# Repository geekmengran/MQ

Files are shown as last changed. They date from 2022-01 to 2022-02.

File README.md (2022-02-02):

### MangoPi Nezha-MQ

### Introduction

This micro development board is specially designed to run Linux. Despite a mini body, it has all the vital functions. Equipped with D1s(RISC-V core) as the maincontroller chip, the board offers various commonly-used peripheral ports: GPIO, I2C & SPI, SDIO, Audio port(record, play), Video(RGB666 Display, touch, DVP, DSI and LVDS), USB Host, OTG, etc. Besides, the board comes with a built-in 64MB DDR and onboard WiFi, which fully supports Linux ecology and running complete Python.

### Spectification
  * D1s with 64MB DDR, RISC-V core up to 1GHz
  * Type-C USB-OTG and HOST
  * 22Pin expand x2(all pins out)
  * TF card
  * RTL8189F WiFi or other WiFi/BT module
  * FPC connector 15Pins DSI, 40Pins RGB, 24Pins DVP/RMII, 6Pins CTP
  * MIC and Audio OUT
  * Fel,reset button
  * 4x4cm size

### PCB
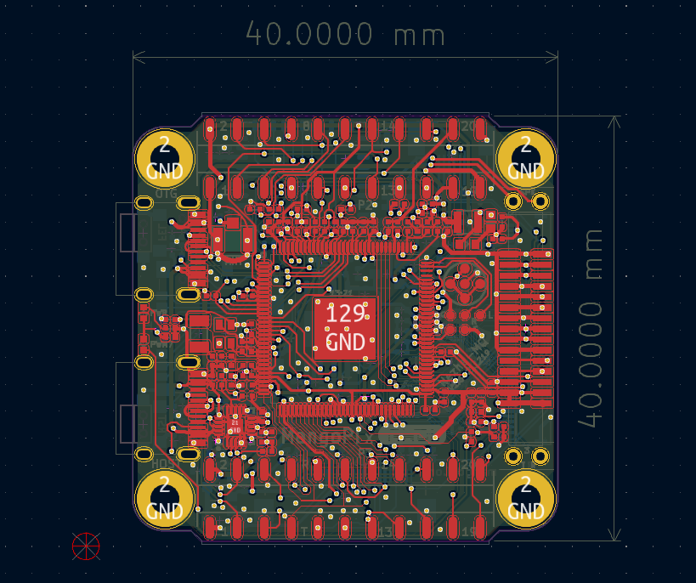
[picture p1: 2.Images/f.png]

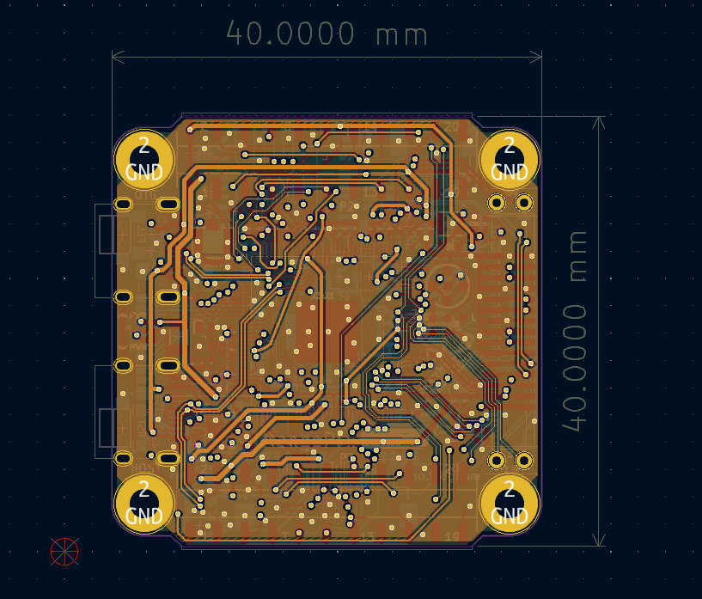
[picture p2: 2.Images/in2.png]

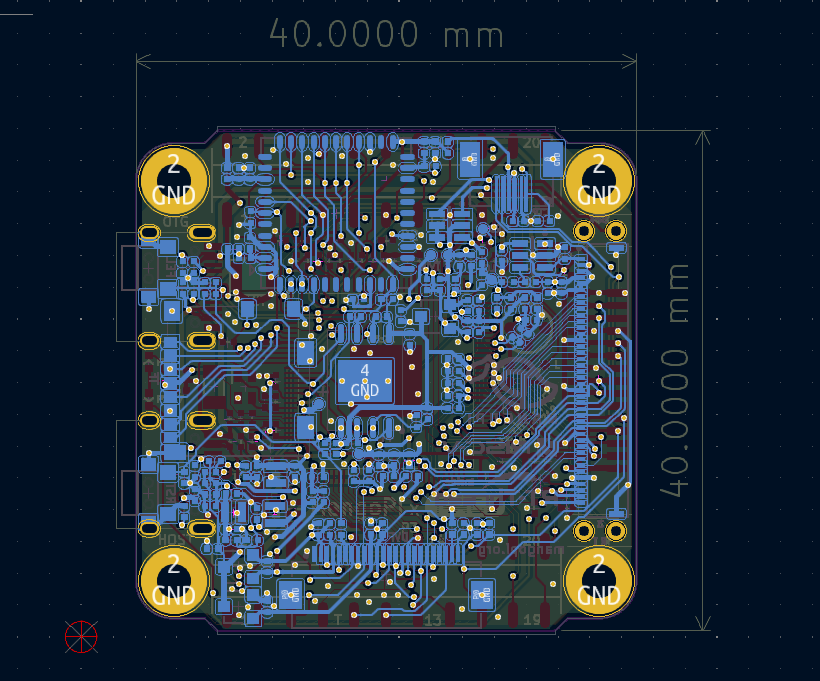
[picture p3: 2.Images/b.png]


### SCH
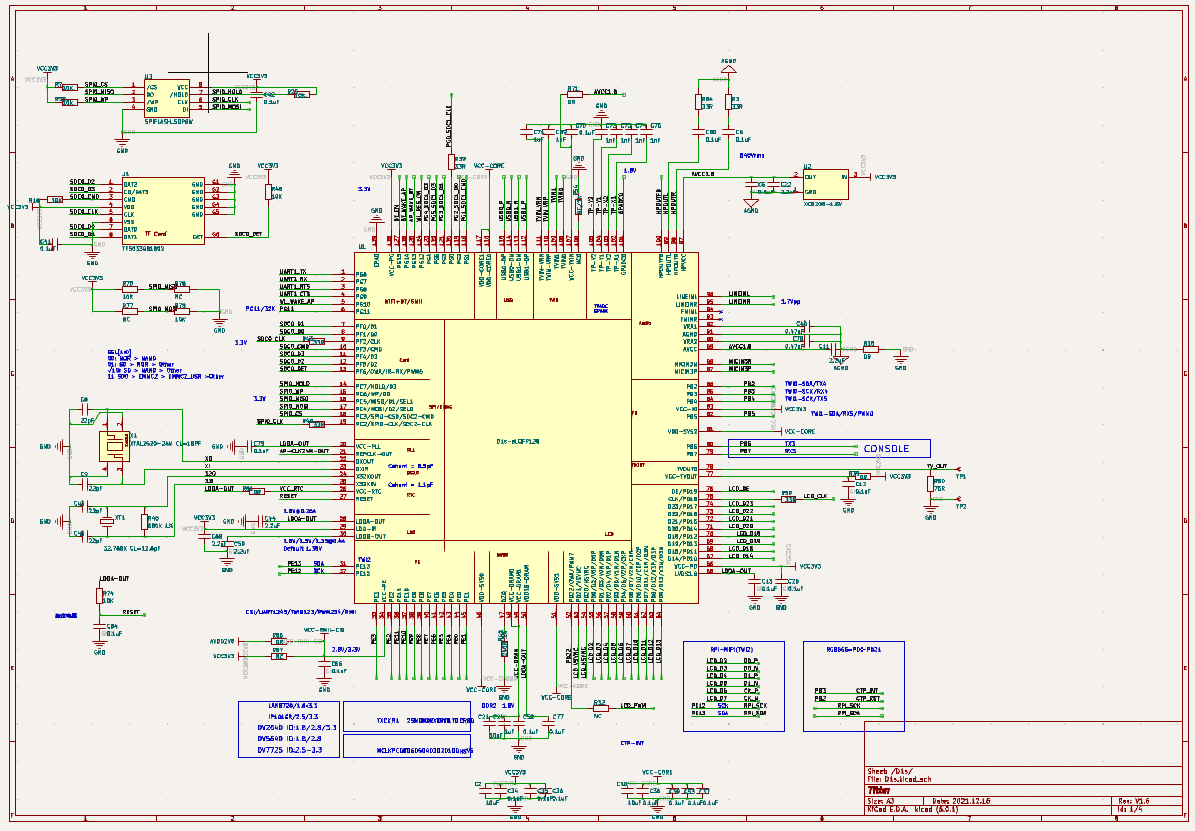
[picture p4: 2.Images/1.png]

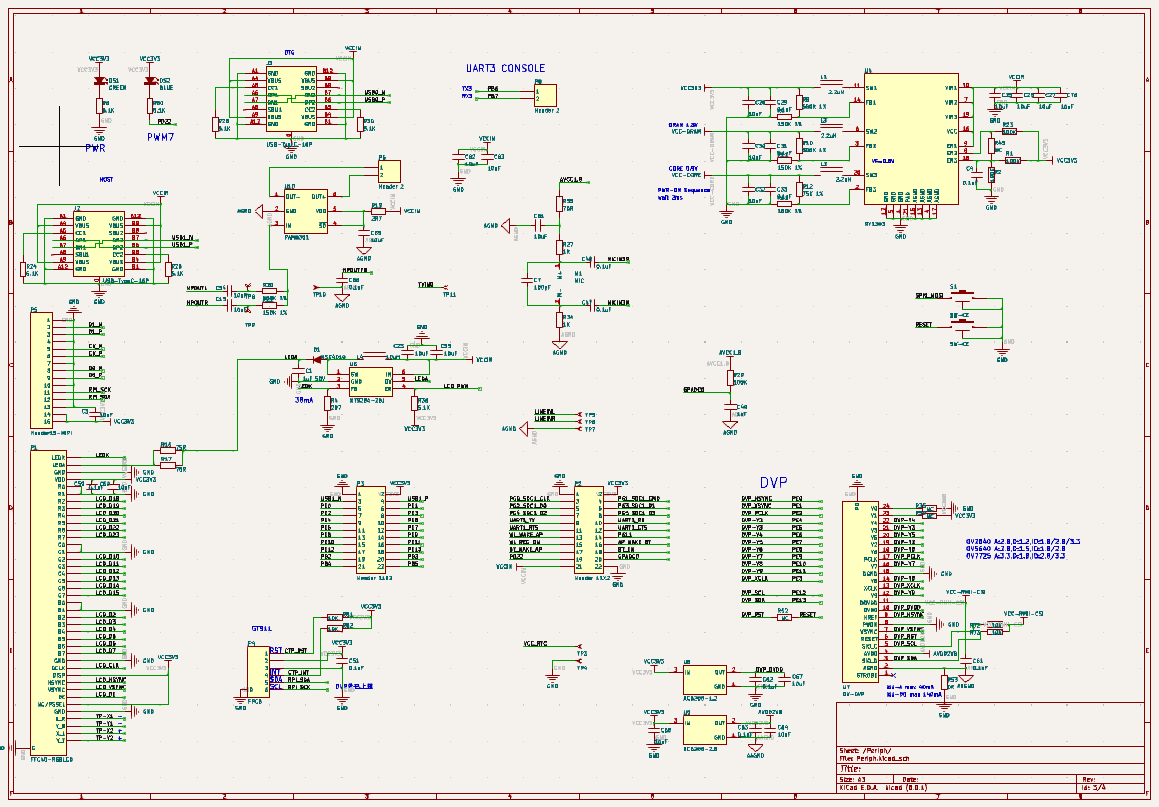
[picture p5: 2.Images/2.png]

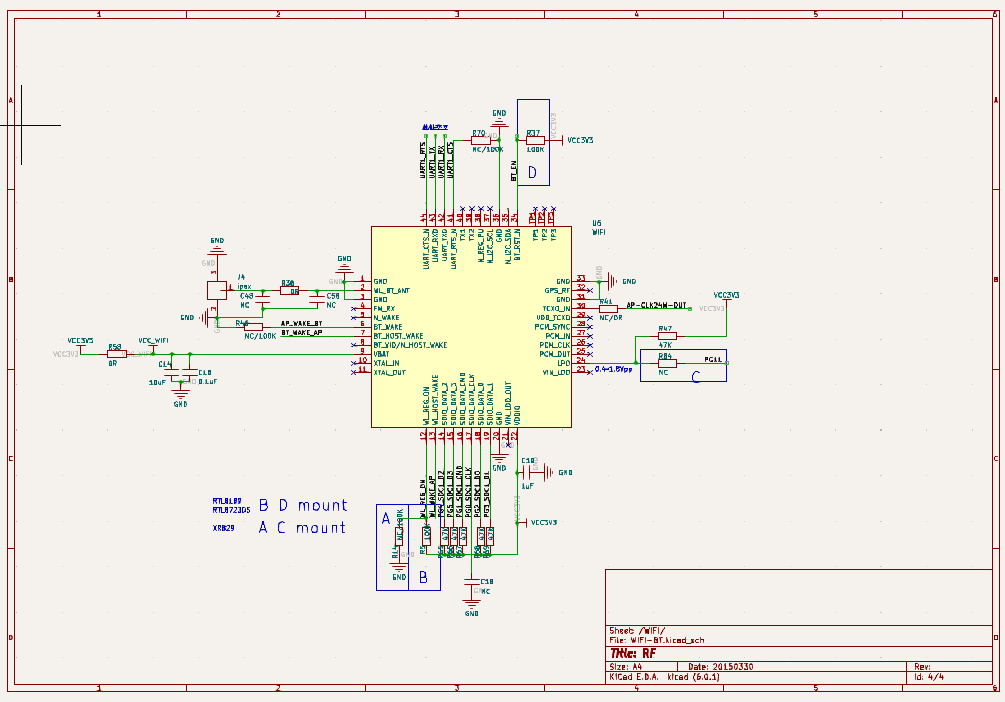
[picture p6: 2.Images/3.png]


### V1.6 Mass-Production
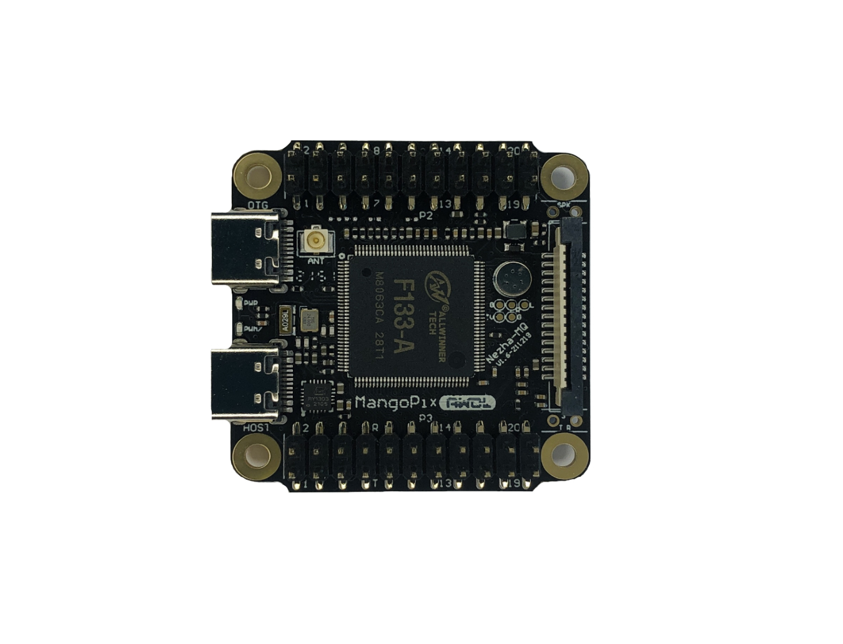
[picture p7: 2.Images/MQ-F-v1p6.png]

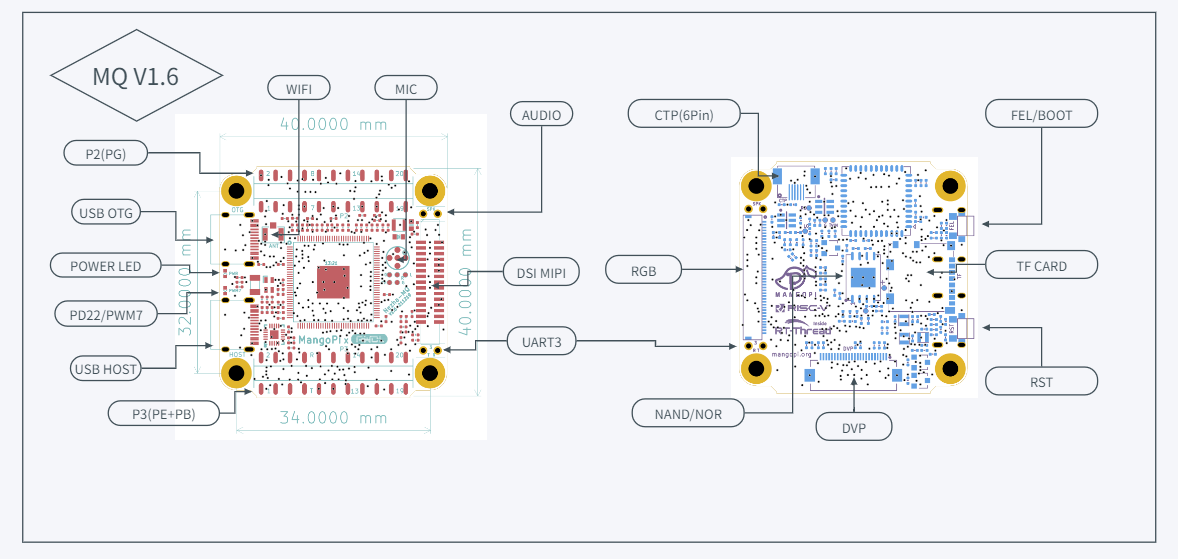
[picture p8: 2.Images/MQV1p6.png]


### MQ on the web
  * [mass-production on twitter]( https://twitter.com/mangopi_sbc/status/1469197984303022080)
  * [A shell](https://twitter.com/mangopi_sbc/status/1472535322605273090)
  * [MoeOS on MQ](https://www.lirui.tech/post/2021/12/MoeOS%E6%90%AC%E5%AE%B6%E5%88%B0Nezha-MQ%E4%B8%8A%E5%95%A6%EF%BC%88D1s%E8%A3%B8%E6%9C%BA%E7%A8%8B%E5%BA%8F%E6%89%A7%E8%A1%8C%EF%B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)
  * [Getting started on MQ with Tina-Linux](https://whycan.com/t_7575.html)
  * [use MQ drive RGB display](https://blog.csdn.net/qq_34440409/article/details/122021748)
  * [MQ first experience](https://www.neko.ooo/mongopi-mq1-hands-on/)
  * [RT-Thread on MQ](https://bbs.aw-ol.com/topic/908/)
  * [MQ's MIPI-DSI](https://bbs.aw-ol.com/topic/808/)
  * [more on Twitter](https://twitter.com/search?q=mangopi)

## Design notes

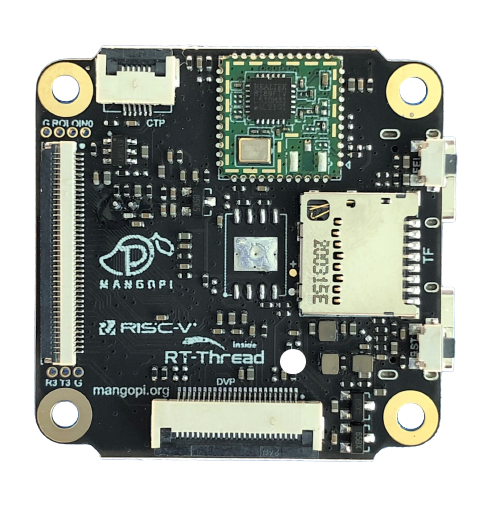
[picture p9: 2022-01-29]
2.Images/MQ-B-v1p5.png

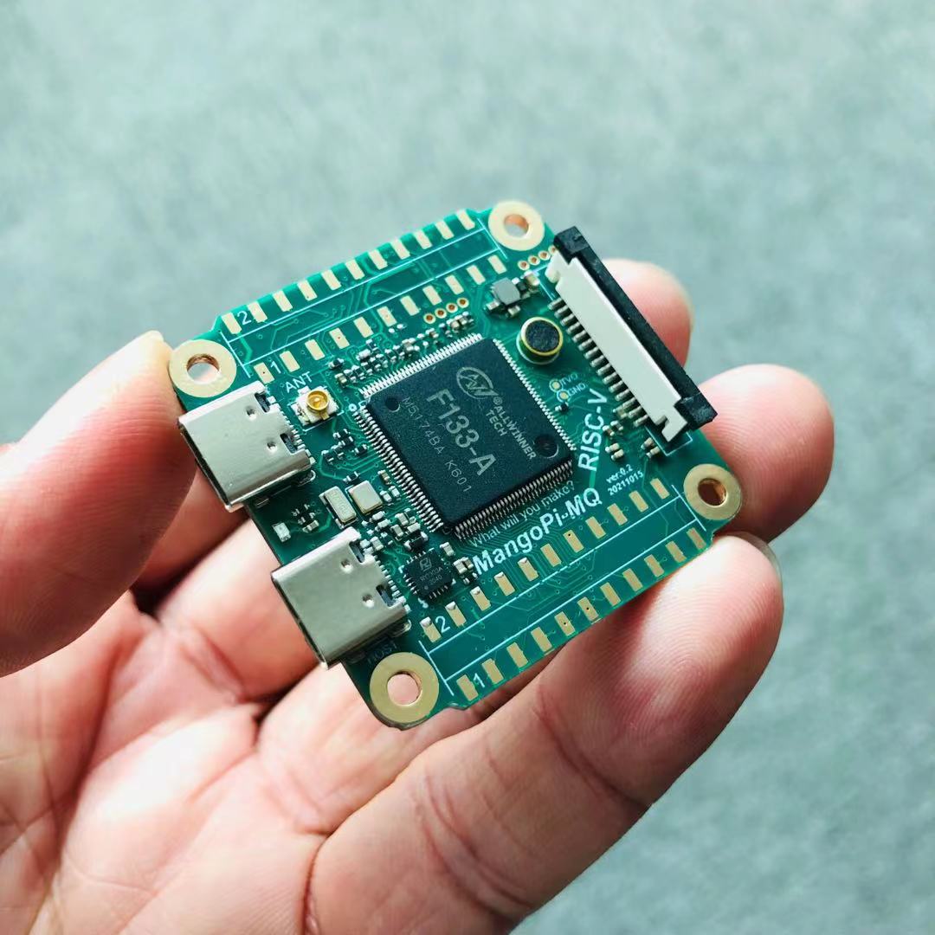
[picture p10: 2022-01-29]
2.Images/v0p2_first_run.jpg

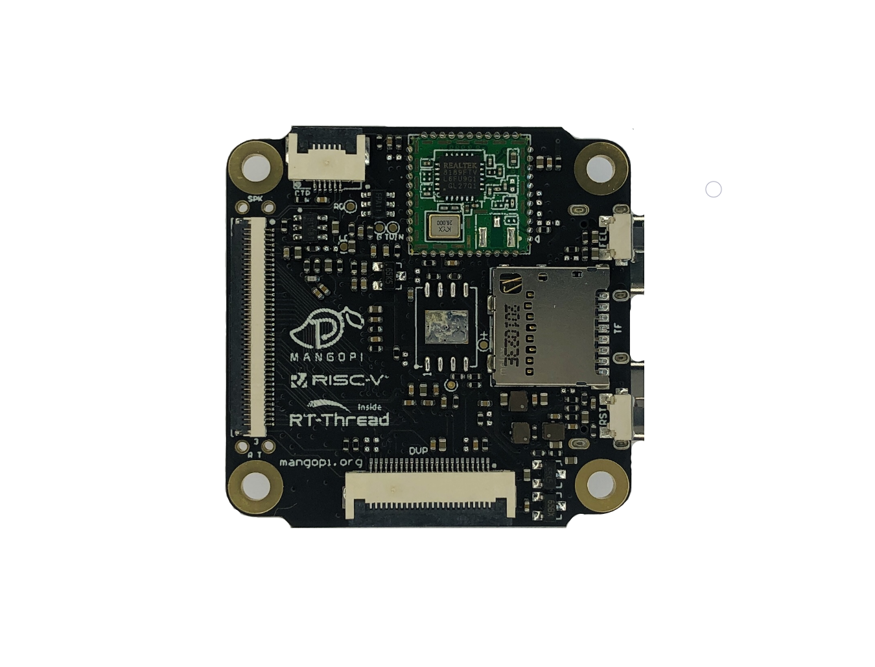
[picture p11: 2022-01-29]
2.Images/MQ-B-V1p6.png

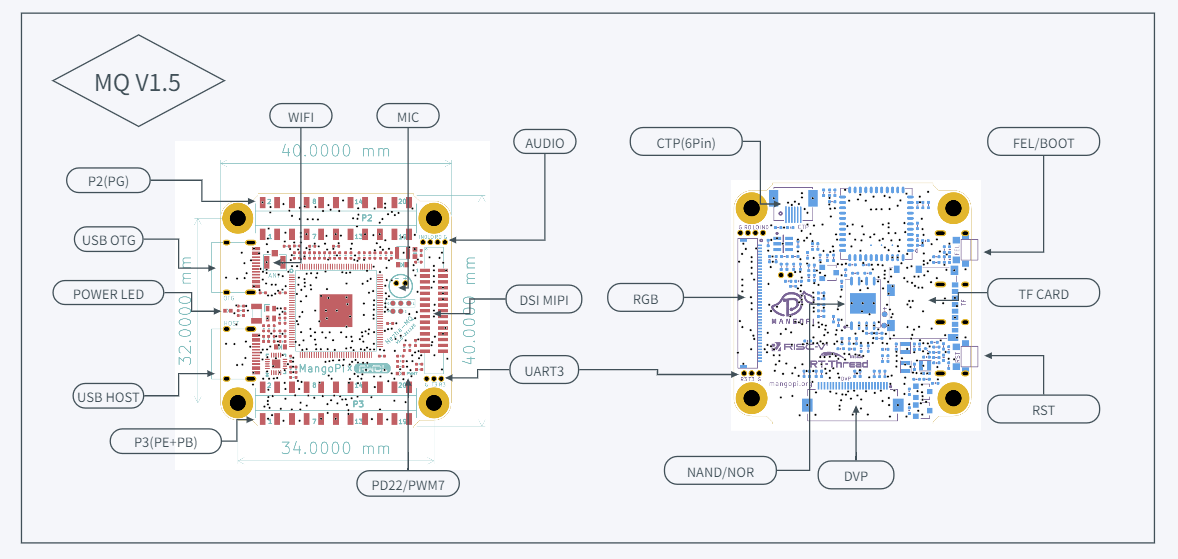
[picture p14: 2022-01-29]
2.Images/MQV1p5.png

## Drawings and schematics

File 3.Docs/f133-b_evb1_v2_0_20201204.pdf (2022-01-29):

# I n d e x ：

Revision | Description | Date | Drawn | Approved Checked

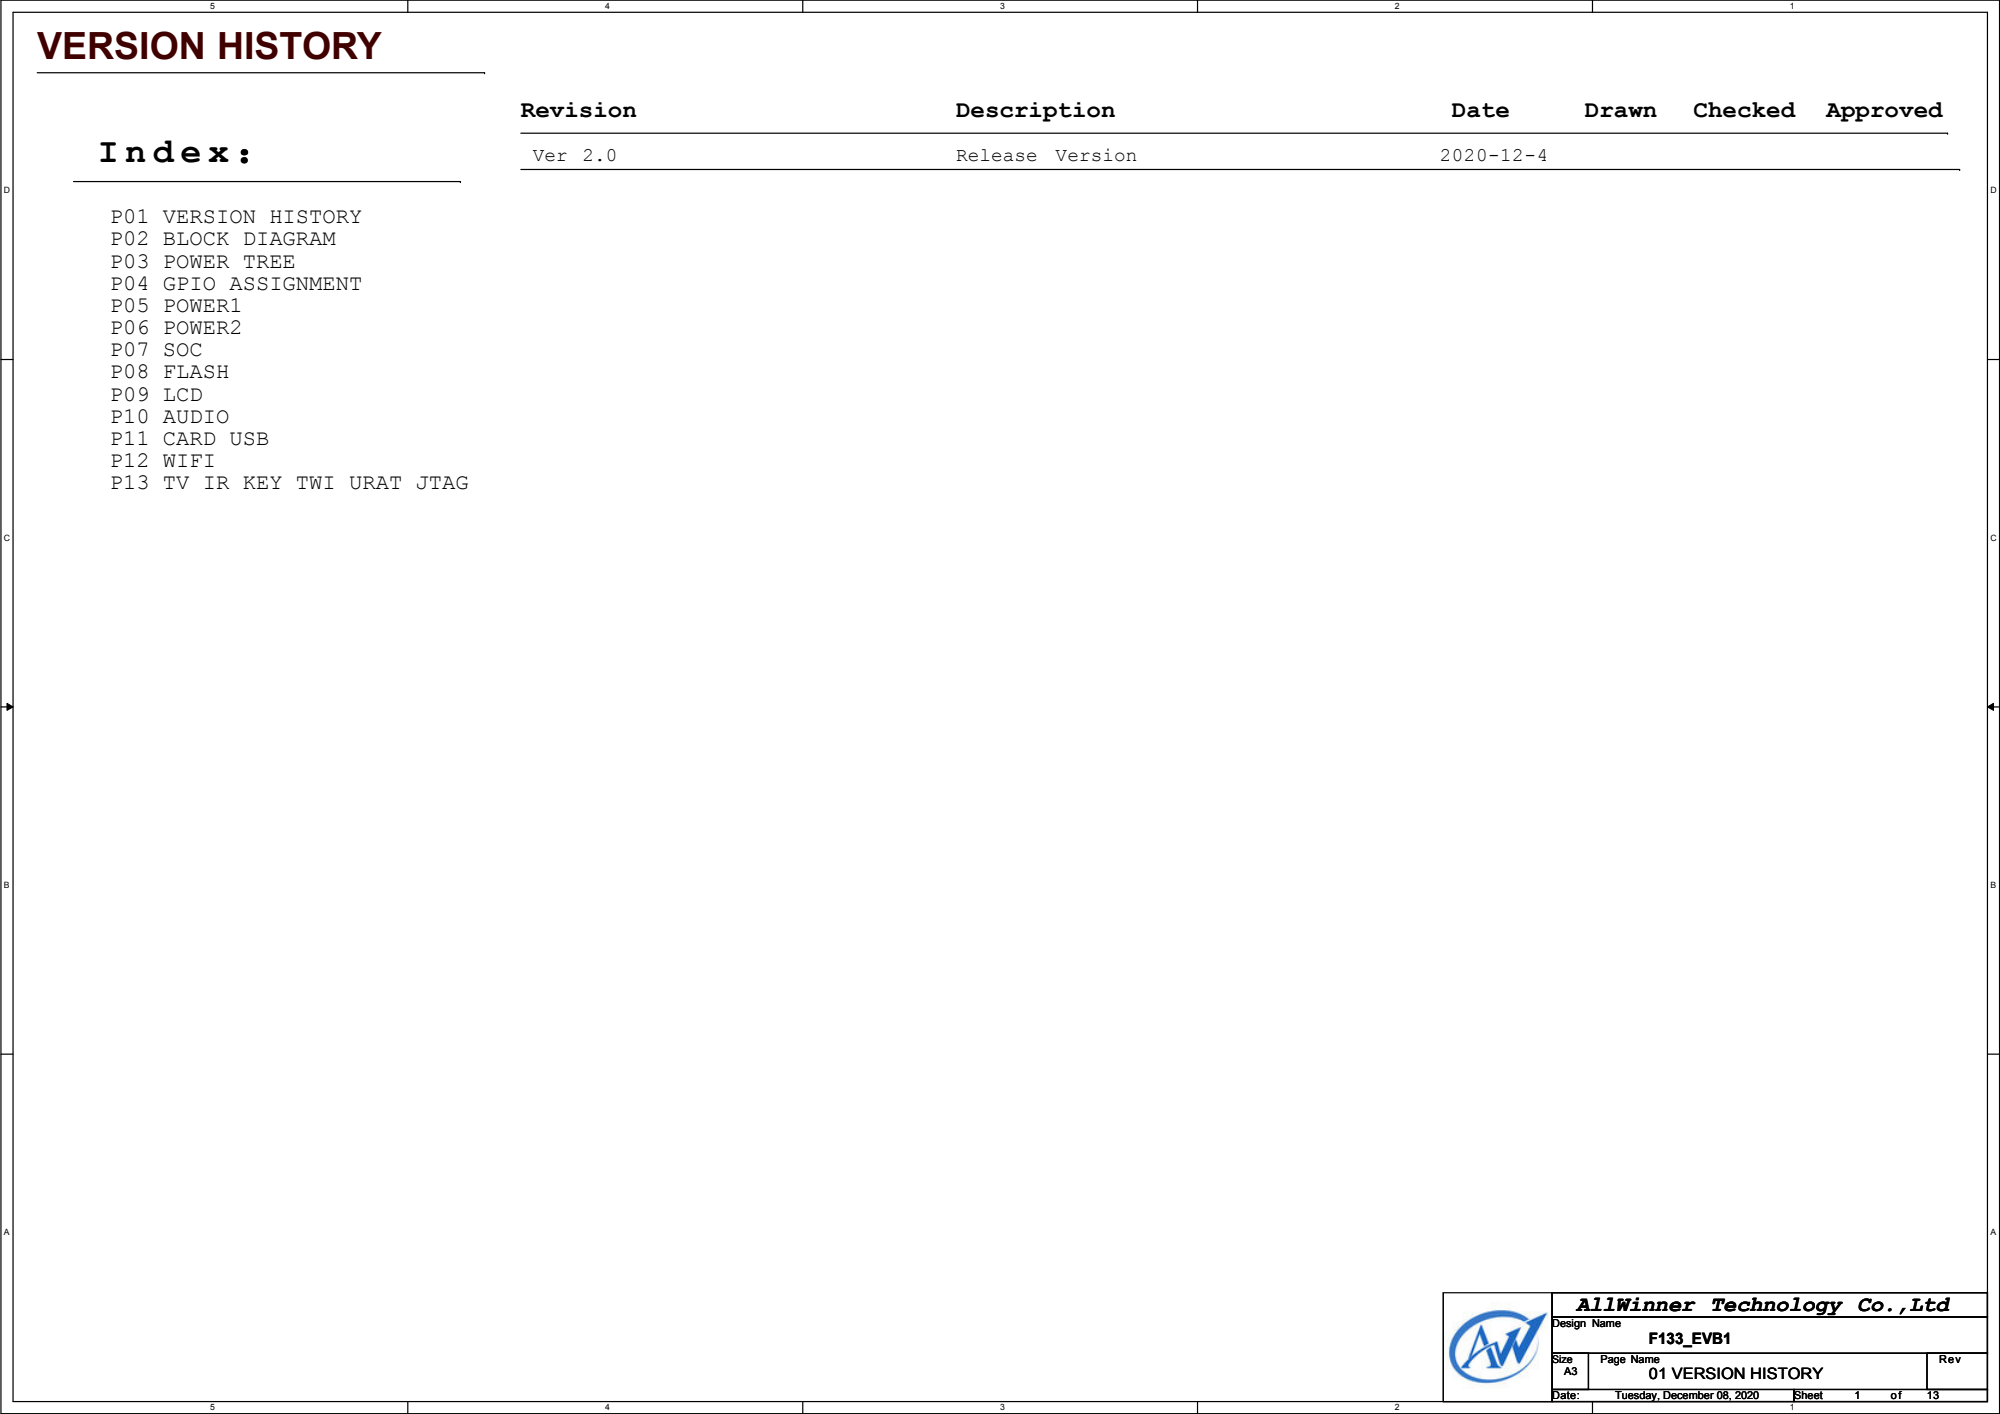
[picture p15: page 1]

AllWinner Technology Co.,Ltd

# BLOCK

## USB1

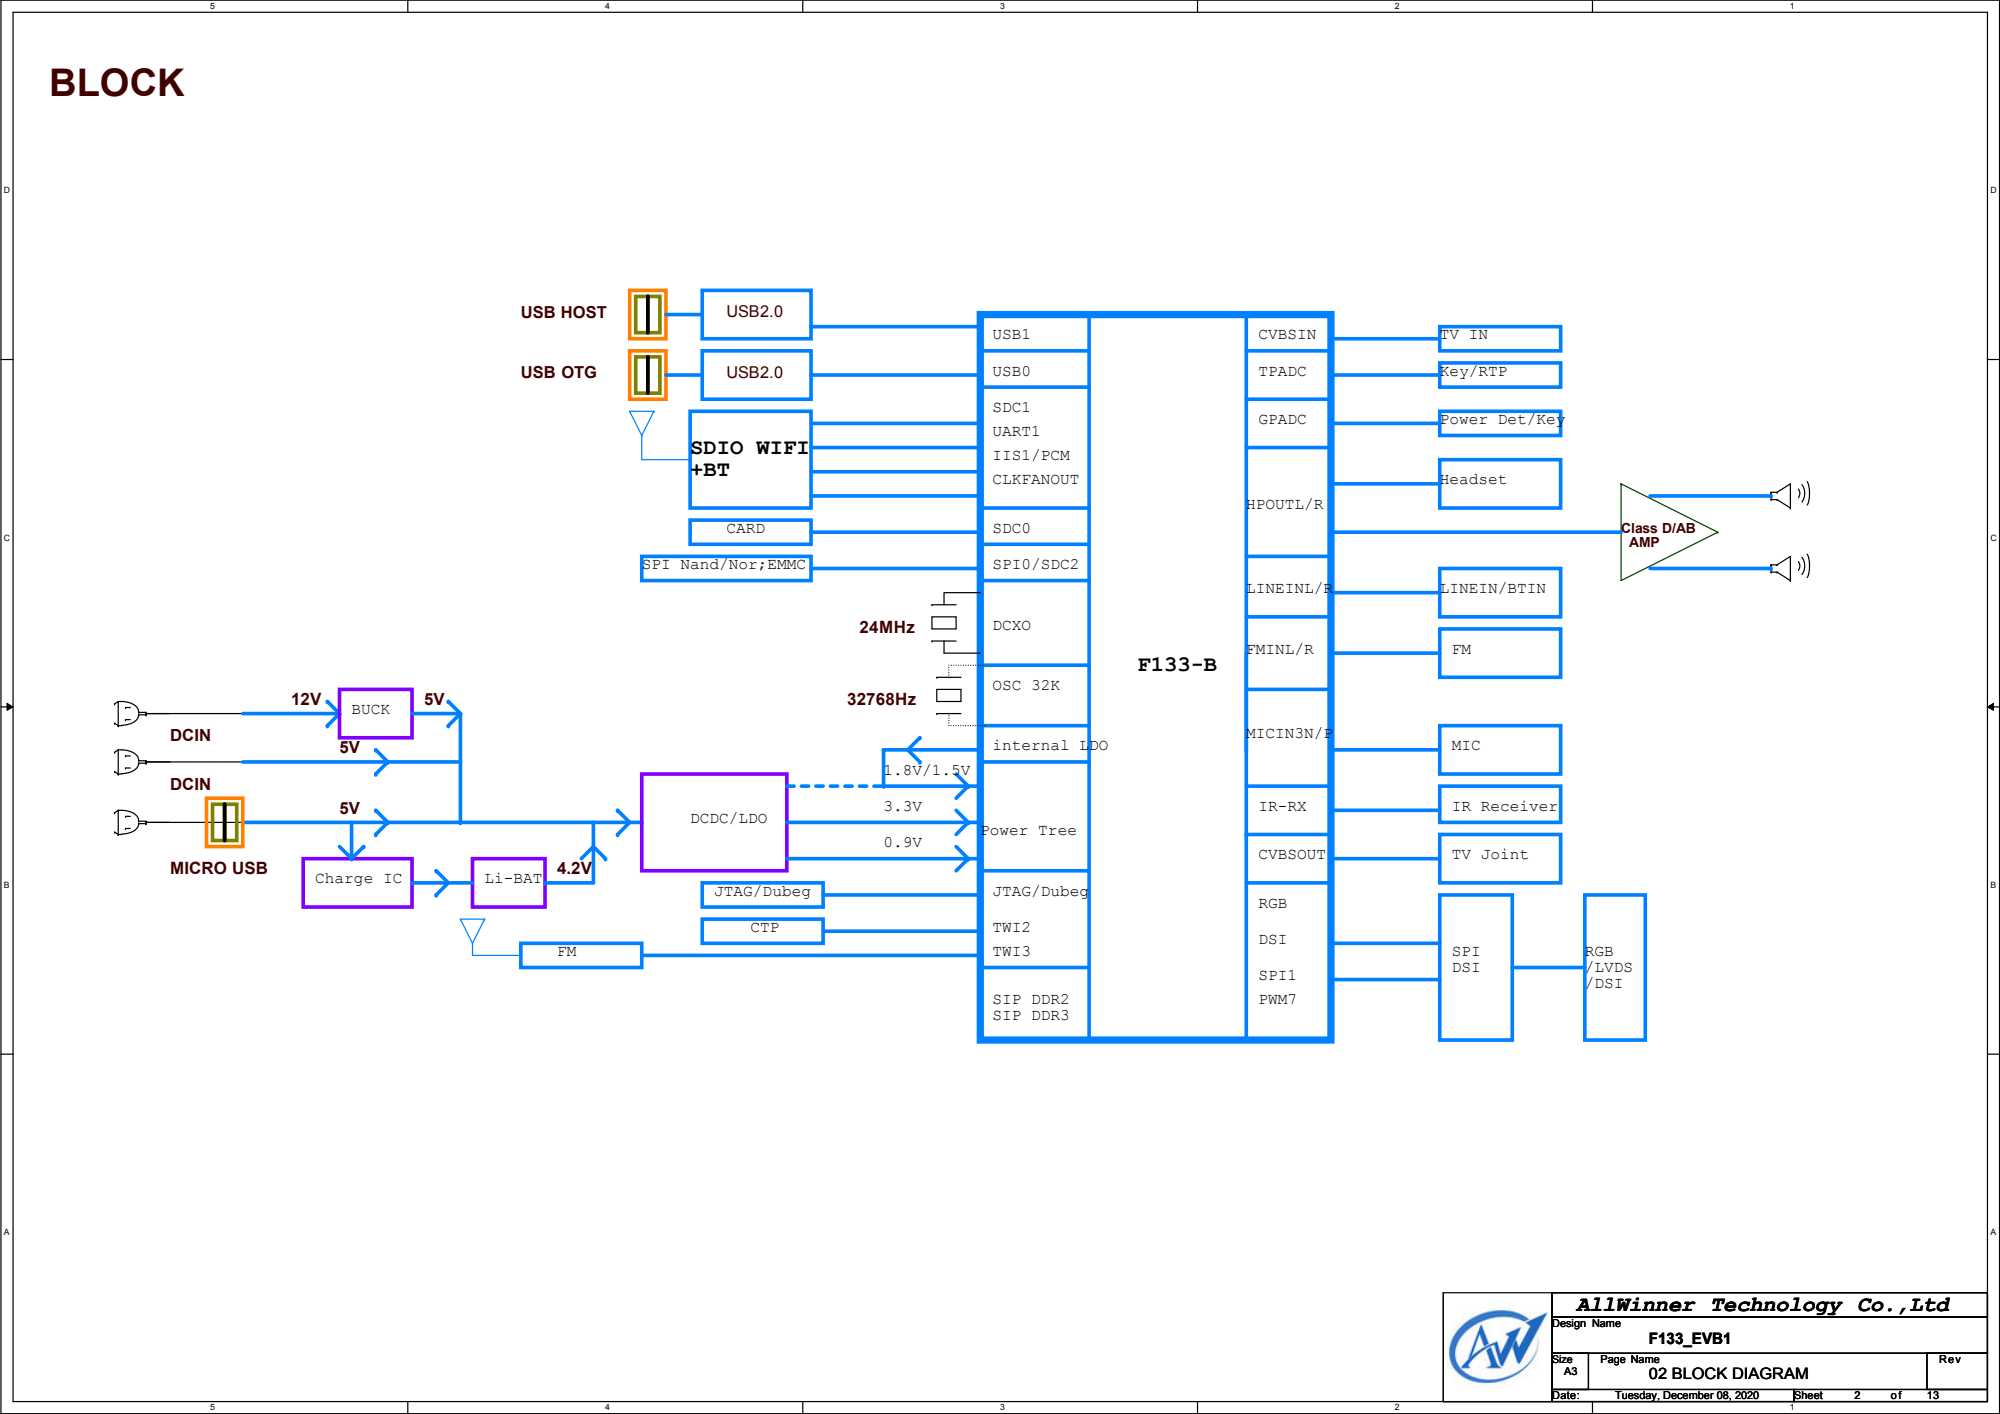
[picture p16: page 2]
HPOUTL/R; DCXO; MICIN3N/P; CLKFANOUT; JTAG/Dubeg; SPI0/SDC2; SDC0; OSC 32K; Power Tree; LINEINL/R; USB0; 24MHz; CVBSIN; TPADC; GPADC; FMINL/R; SDC1; UART1; IIS1/PCM; SIP DDR2 SIP DDR3; RGB; DSI; internal LDO; Li-BAT; MICRO USB; DCDC/LDO; Charge IC; DCIN; BUCK; USB OTG; USB2.0; USB HOST; SDIO WIFI +BT; CARD; TWI3; CTP; TWI2; PWM7; CVBSOUT; SPI1; TV Joint; IR Receiver; MIC; LINEIN/BTIN; Class D/AB AMP; Headset; Key/RTP; SPI DSI; RGB /LVDS /DSI; 02 BLOCK DIAGRAM; Tuesday, December 08, 2020

Power Det/Key

SPI Nand/Nor;EMMC

## 5V VCC-5V-USB/VCC-5V-LCD/VCC-5V-WIFI(ON)

# DEFAULT POWER ON

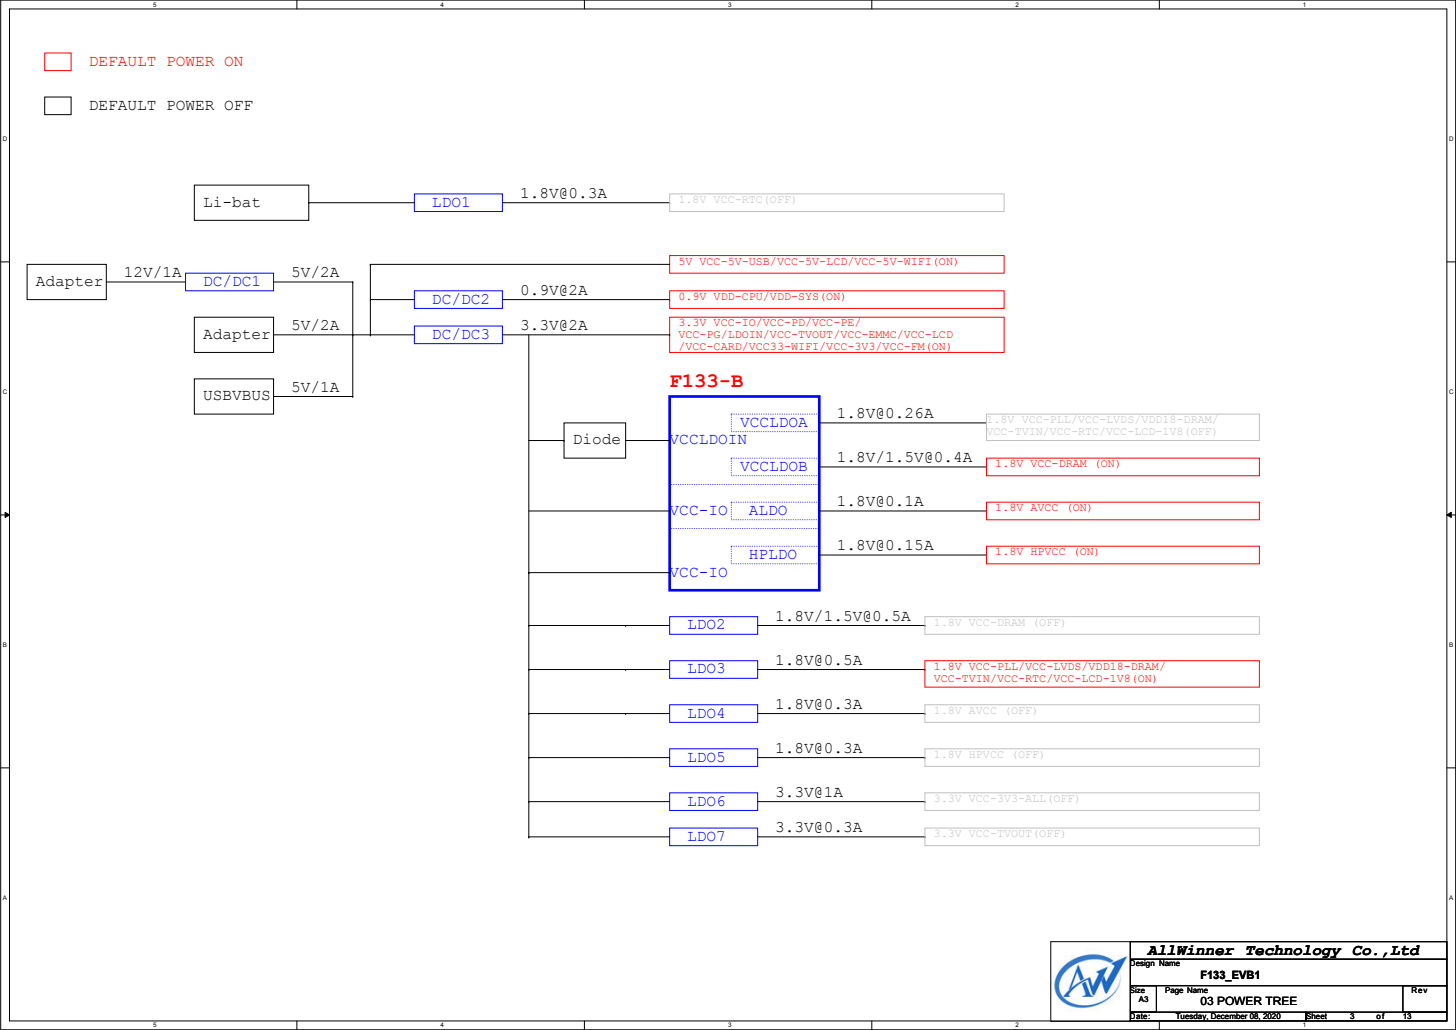
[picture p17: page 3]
Adapter; LDO2; LDO3; VCCLDOA; VCCLDOB; ALDO; HPLDO; VCCLDOIN; VCC-IO; LDO4; LDO5; Diode; Li-bat; LDO1; USBVBUS; 3.3V@1A LDO6; 3.3V VCC-3V3-ALL(OFF); 3.3V@0.3A LDO7; 3.3V VCC-TVOUT(OFF); 1.8V HPVCC (OFF); 1.8V AVCC (OFF); 1.8V HPVCC (ON); 1.8V AVCC (ON); 03 POWER TREE; Tuesday, December 08, 2020

DEFAULT POWER OFF

1.8V VCC-RTC(OFF)

0.9V VDD-CPU/VDD-SYS(ON)

3.3V VCC-IO/VCC-PD/VCC-PE/
VCC-PG/LDOIN/VCC-TVOUT/VCC-EMMC/VCC-LCD
/VCC-CARD/VCC33-WIFI/VCC-3V3/VCC-FM(ON)

1.8V VCC-PLL/VCC-LVDS/VDD18-DRAM/
VCC-TVIN/VCC-RTC/VCC-LCD-1V8(OFF)

1.8V VCC-DRAM (ON)

1.8V VCC-DRAM (OFF)

VCC-TVIN/VCC-RTC/VCC-LCD-1V8(ON)

D | D
C | C
B | B
A | A
Pin Number | Pin Name | Signal Type | Multi2 | Multi3 | Multi4 | Multi5 | Multi6 | Multi7 | Multi8 | Multi14
1 | PG6 | I/O | UART1_TX | TWI2_SCK | RGMII_TXD2 | PWM1 | | | | PG_EINT6
2 | PG7 | I/O | UART1_RX | TWI2_SDA | RGMII_TXD3 | SPDIF_IN | | | | PG_EINT7
3 | PG8 | I/O | UART1_RTS | TWI1_SCK | RGMII_RXD2 | UART3_TX | | | | PG_EINT8
4 | PG9 | I/O | UART1_CTS | TWI1_SDA | RGMII_RXD3 | UART3_RX | | | | PG_EINT9
5 | PG10 | I/O | PWM3 | TWI3_SCK | RGMII_RXCK | CLK_FANOUT0IR_RX | | | | PG_EINT10
6 | PG11 | I/O | I2S1_MCLK | TWI3_SDA | EPHY_25M | CLK_FANOUT1TCON_TRIG | | | | PG_EINT11
7 | PF0 | I/O | SDC0_D1 | JTAG_MS | R_JTAG_MS | I2S2_DOUT1 | I2S2_DIN0 | | | PF_EINT0
8 | PF1 | I/O | SDC0_D0 | JTAG_DI | R_JTAG_DI | I2S2_DOUT0 | I2S2_DIN1 | | | PF_EINT1
9 | PF2 | I/O | SDC0_CLK | UART0_TX | TWI0_SCK | LEDC_DO | SPDIF_IN | | | PF_EINT2
10 | PF3 | I/O | SDC0_CMD | JTAG_DO | R_JTAG_DO | I2S2_BCLK | | | | PF_EINT3
11 | PF4 | I/O | SDC0_D3 | UART0_RX | TWI0_SDA | PWM6 | IR_TX | | | PF_EINT4
12 | PF5 | I/O | SDC0_D2 | JTAG_CK | R_JTAG_CK | I2S2_LRCK | | | | PF_EINT5

# GPIO ASSIGNMENT

## 04 GPIO ASSIGNMENT

Friday, December 04, 2020 | 4 | 13

## 04 GPIO ASSIGNMENT

Friday, December 04, 2020 | 4 | 13

## 04 GPIO ASSIGNMENT

Friday, December 04, 2020 | 4 | 13

# POWER 1

# 5V INPUT

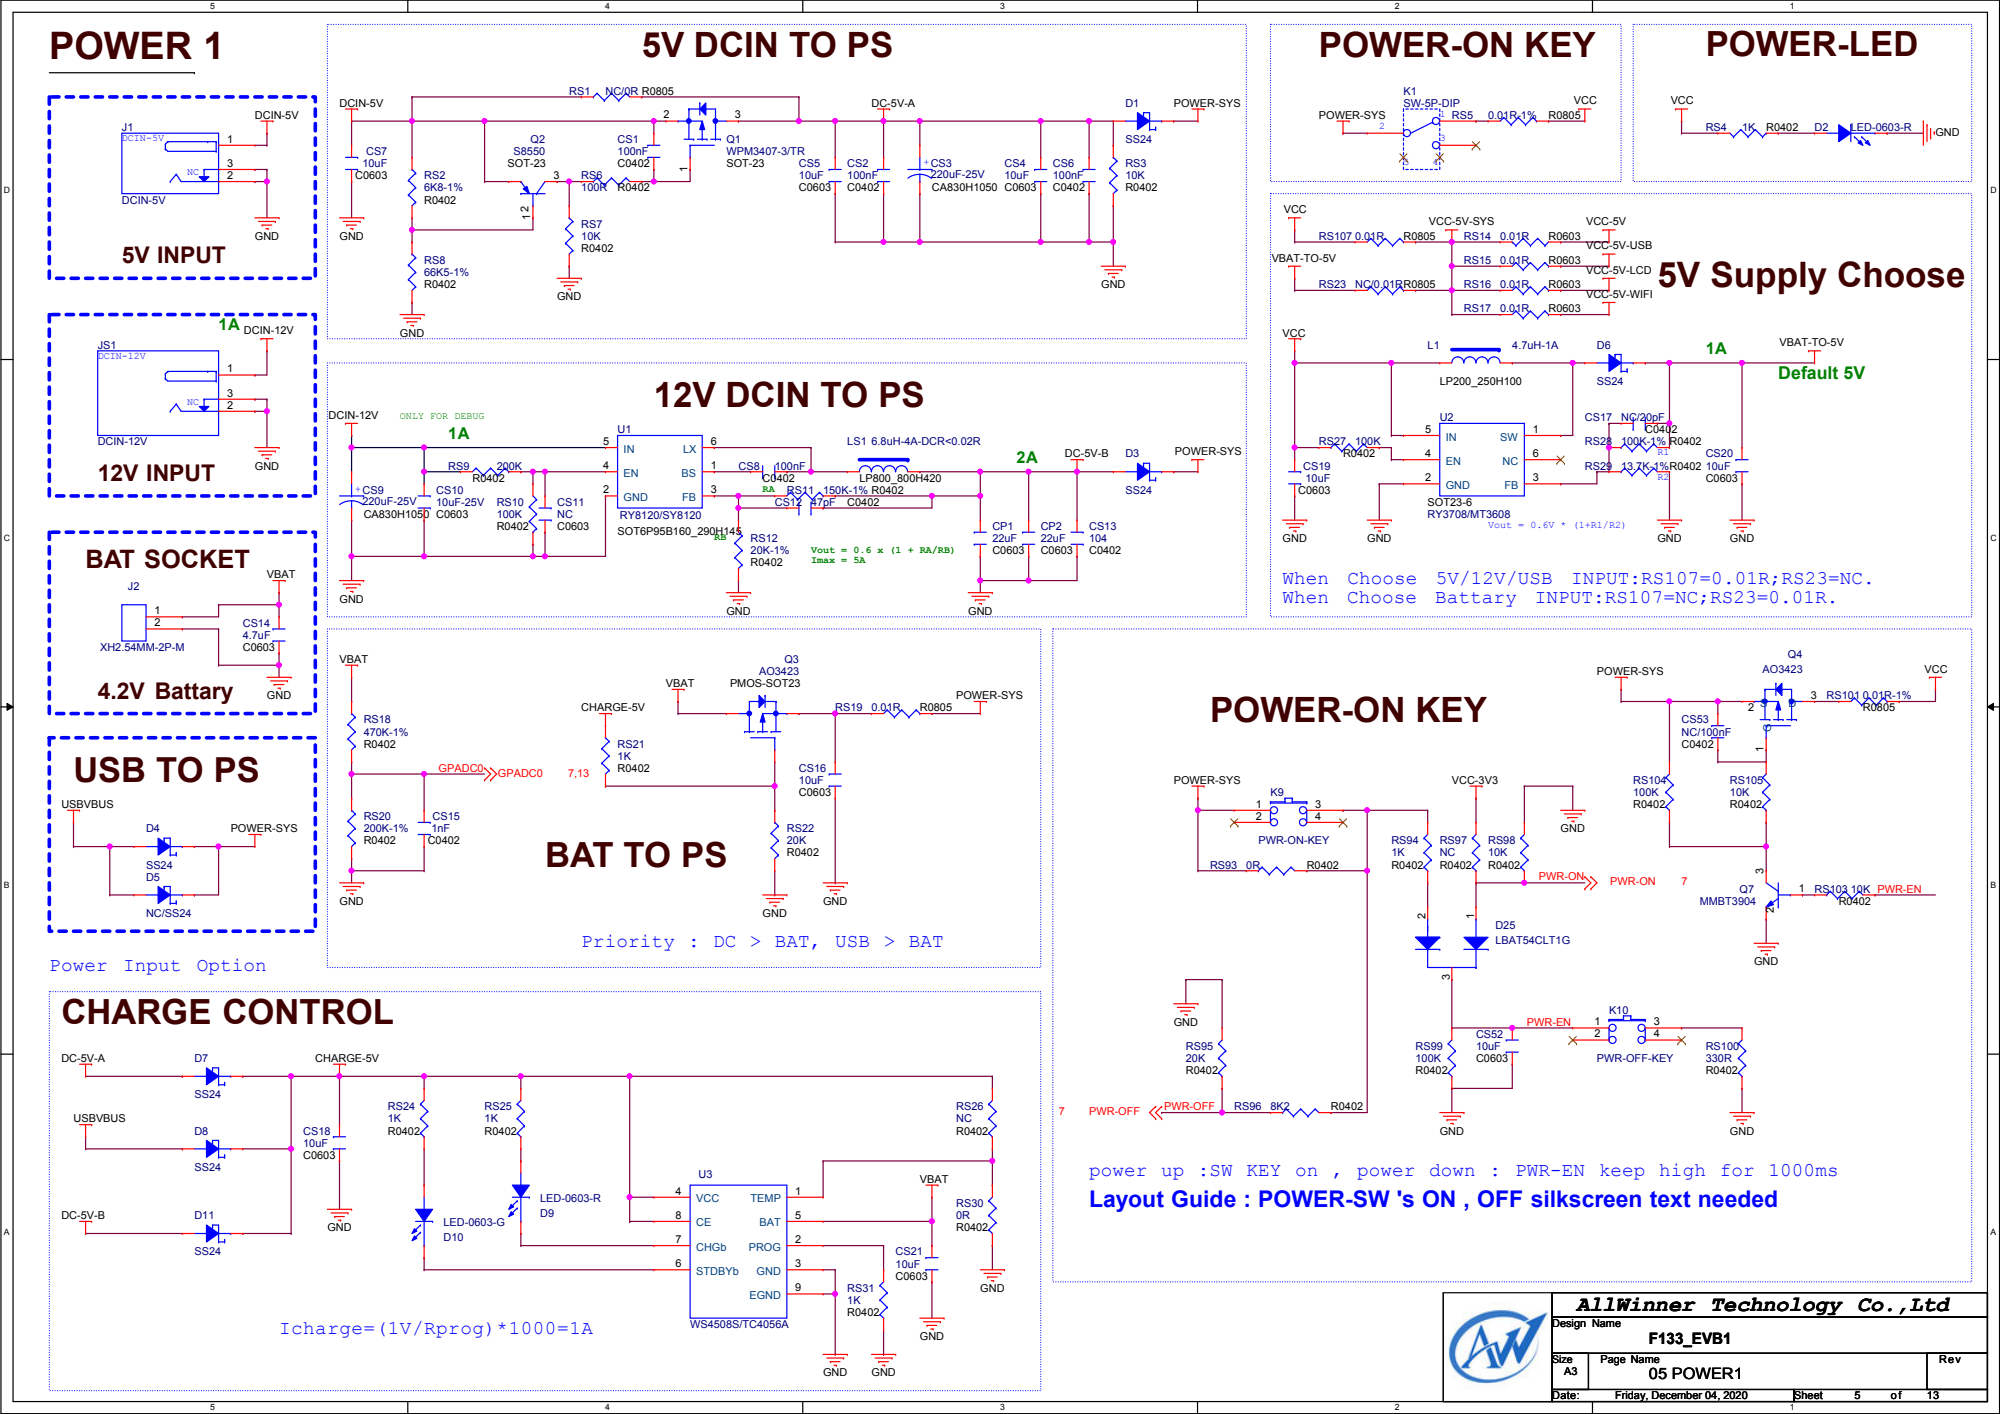
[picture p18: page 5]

When Choose 5V/12V/USB INPUT:RS107=0.01R;RS23=NC.
When Choose Battary INPUT:RS107=NC;RS23=0.01R.

Priority : DC > BAT, USB > BAT

power up :SW KEY on , power down : PWR-EN keep high for 1000ms
Layout Guide : POWER-SW 's ON , OFF silkscreen text needed

# POWER 2

2A

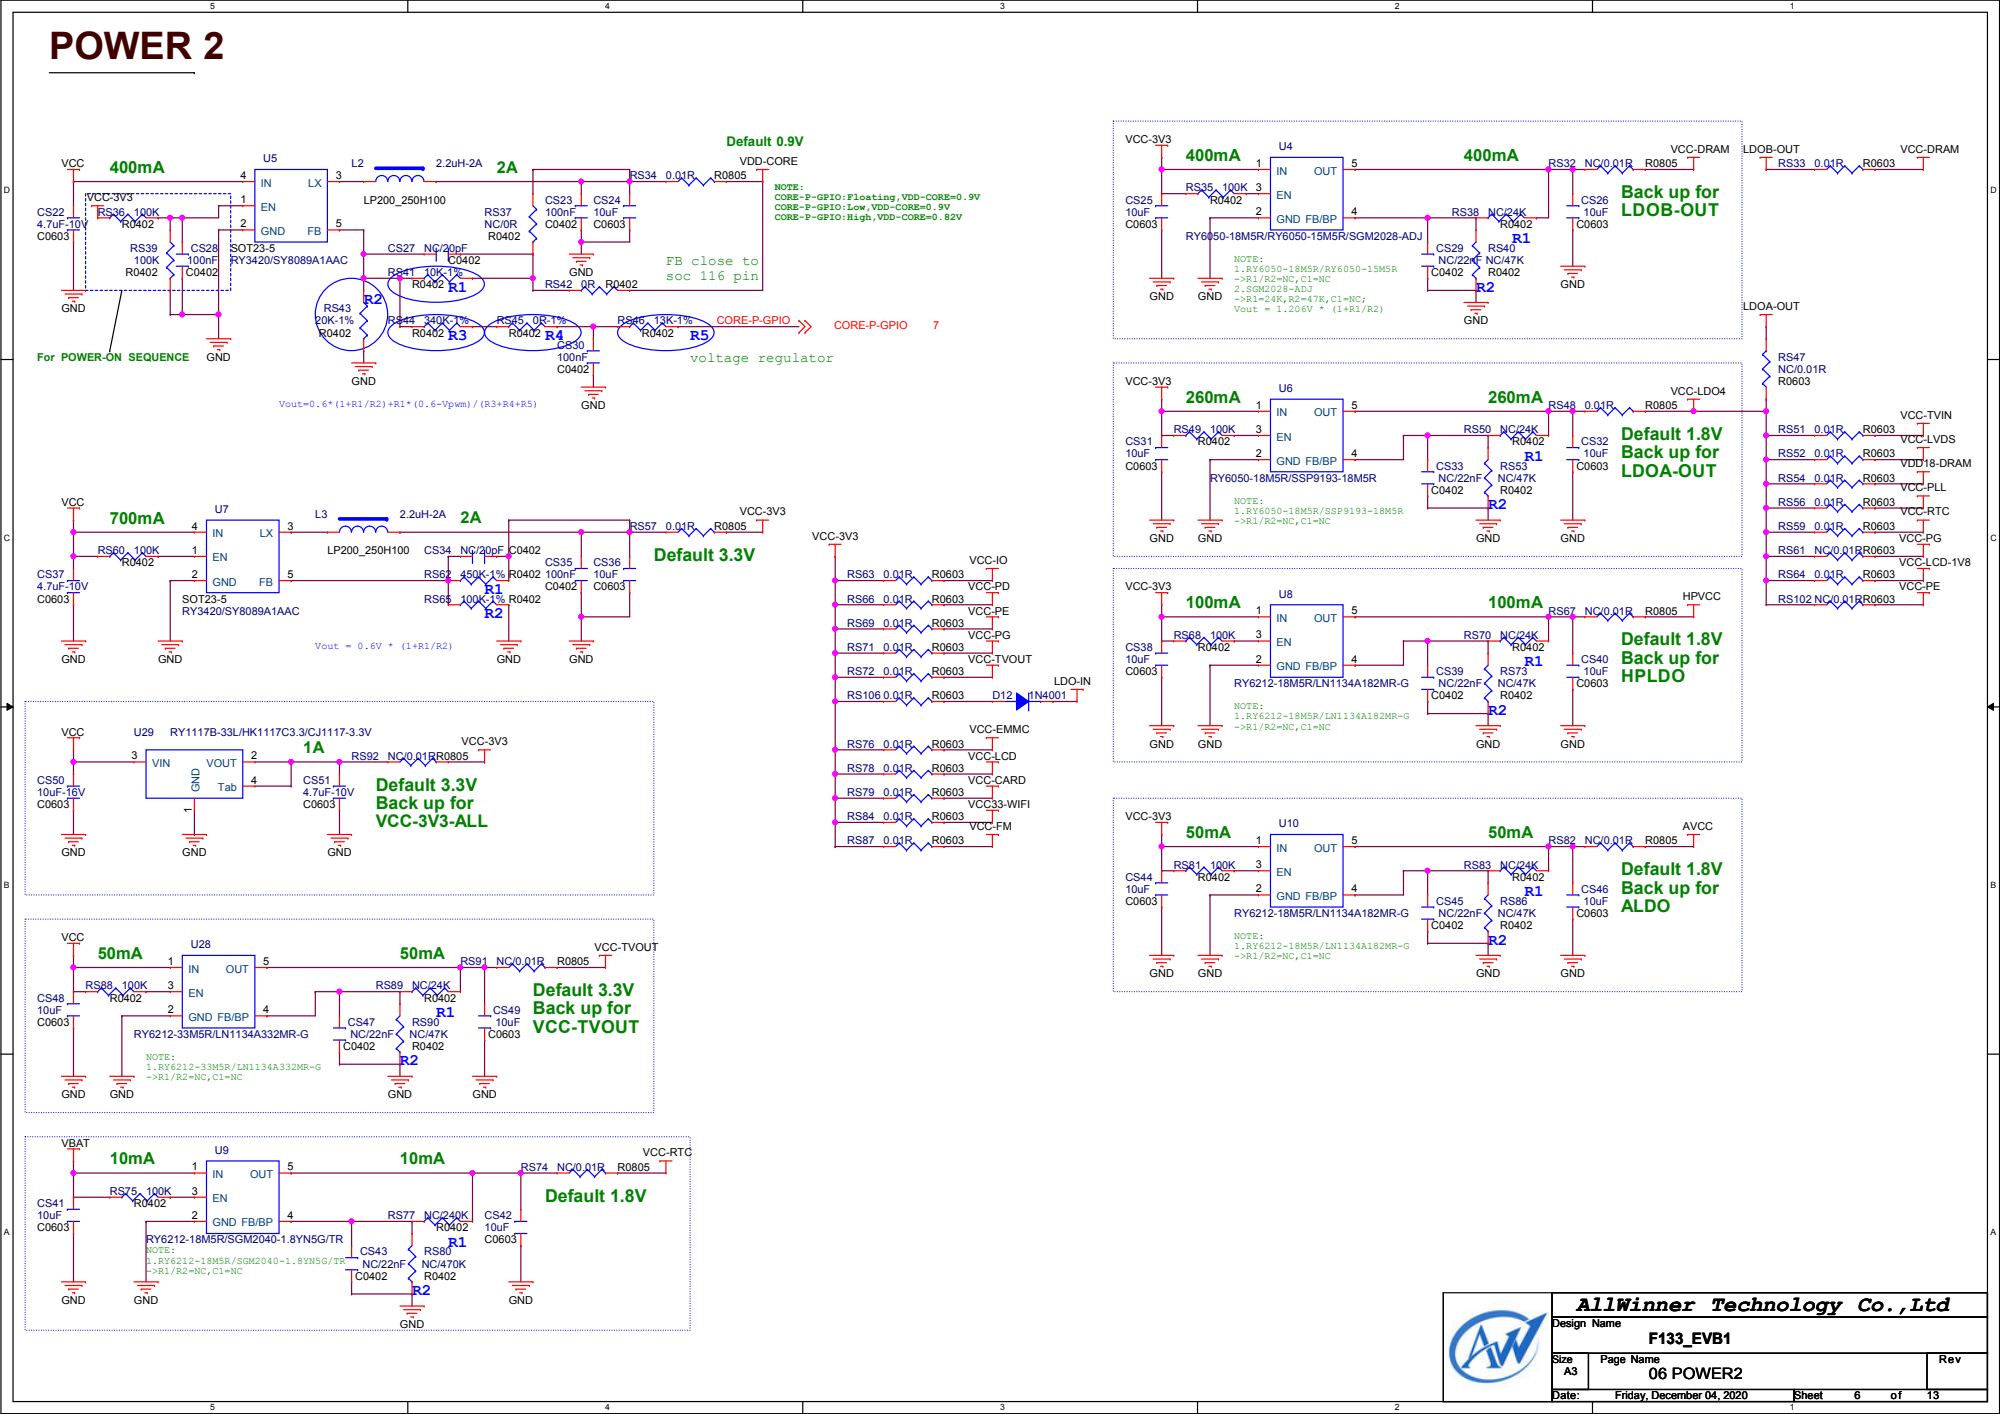
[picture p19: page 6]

NOTE:
CORE-P-GPIO:Floating,VDD-CORE=0.9V
CORE-P-GPIO:Low,VDD-CORE=0.9V
CORE-P-GPIO:High,VDD-CORE=0.82V

For POWER-ON SEQUENCE

# SOC

## Upper left signal

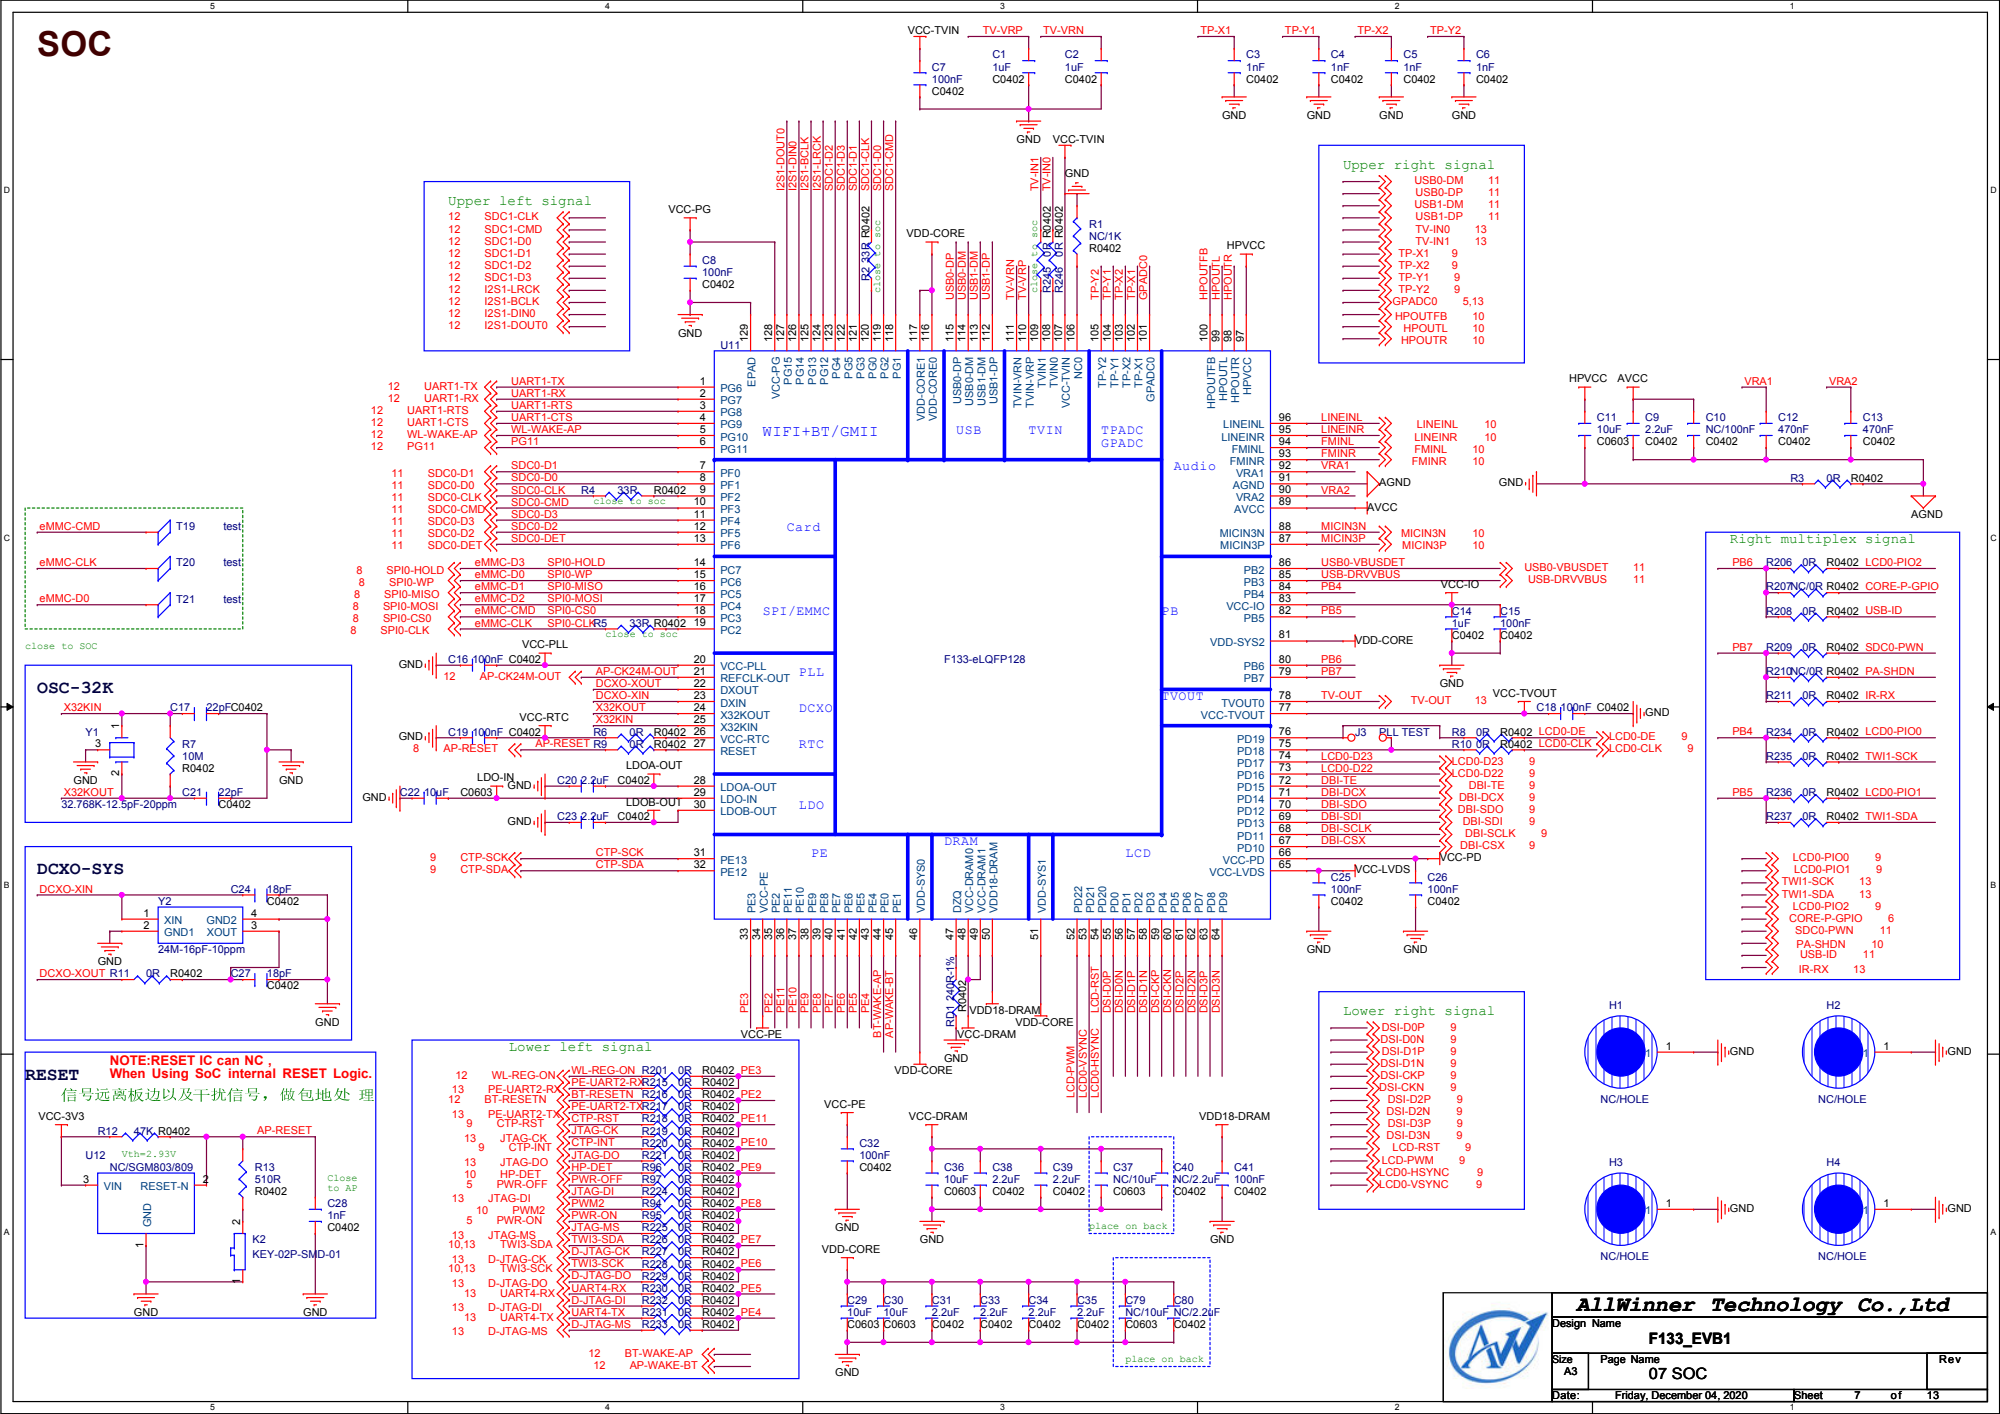
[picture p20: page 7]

NOTE:RESET IC can NC ,
When Using SoC internal RESET Logic.

# SPI

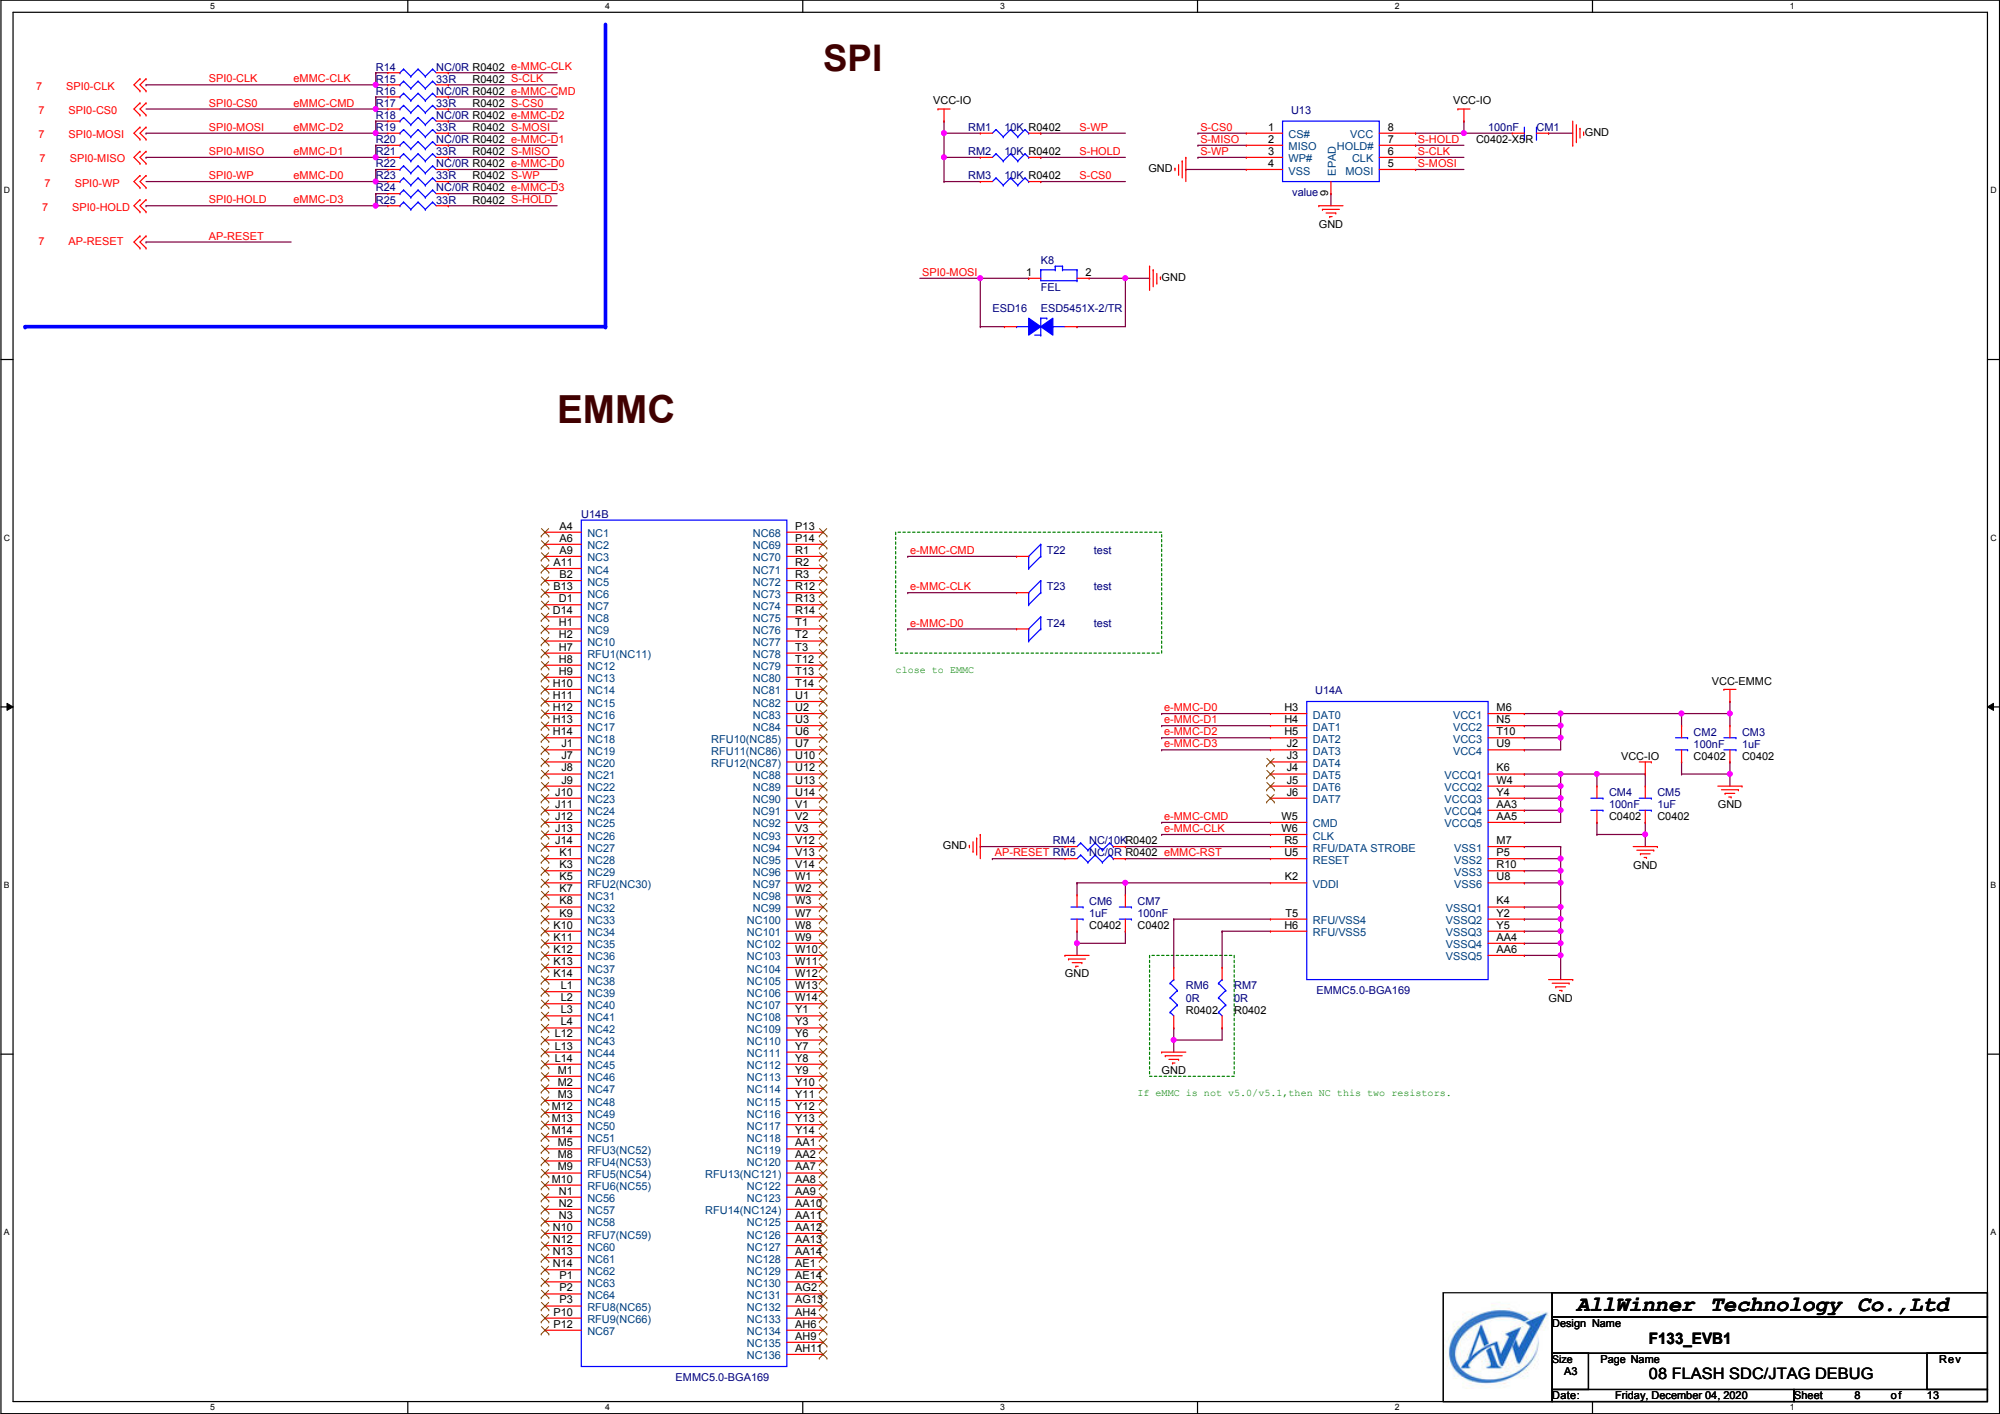
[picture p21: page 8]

If eMMC is not v5.0/v5.1,then NC this two resistors.

08 FLASH SDC/JTAG DEBUG

# DSI BACK LIGHT

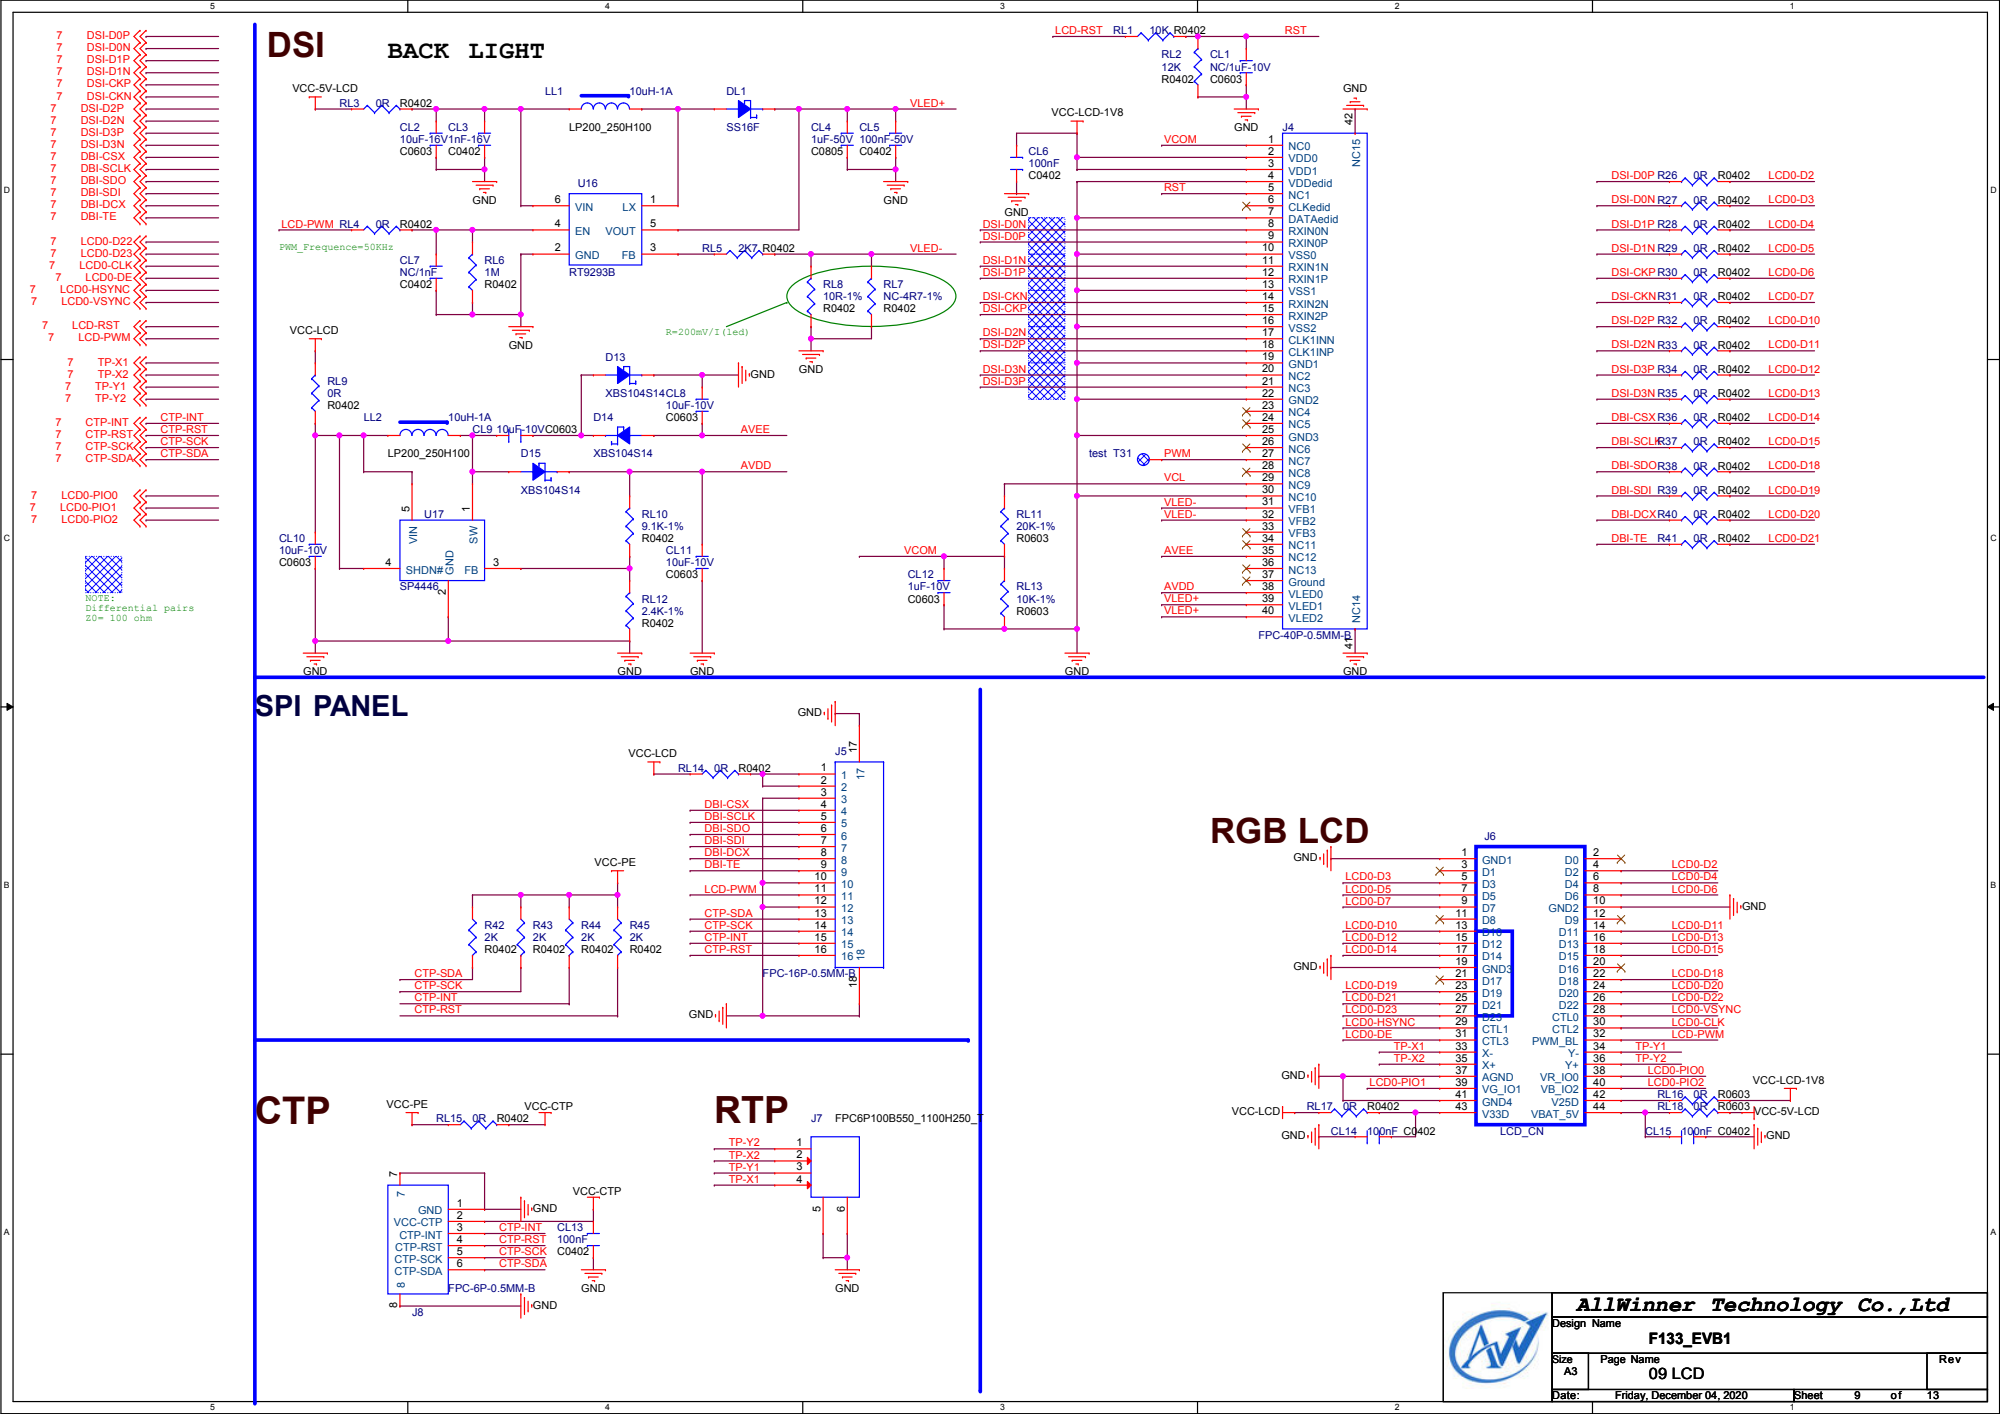
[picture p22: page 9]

FM

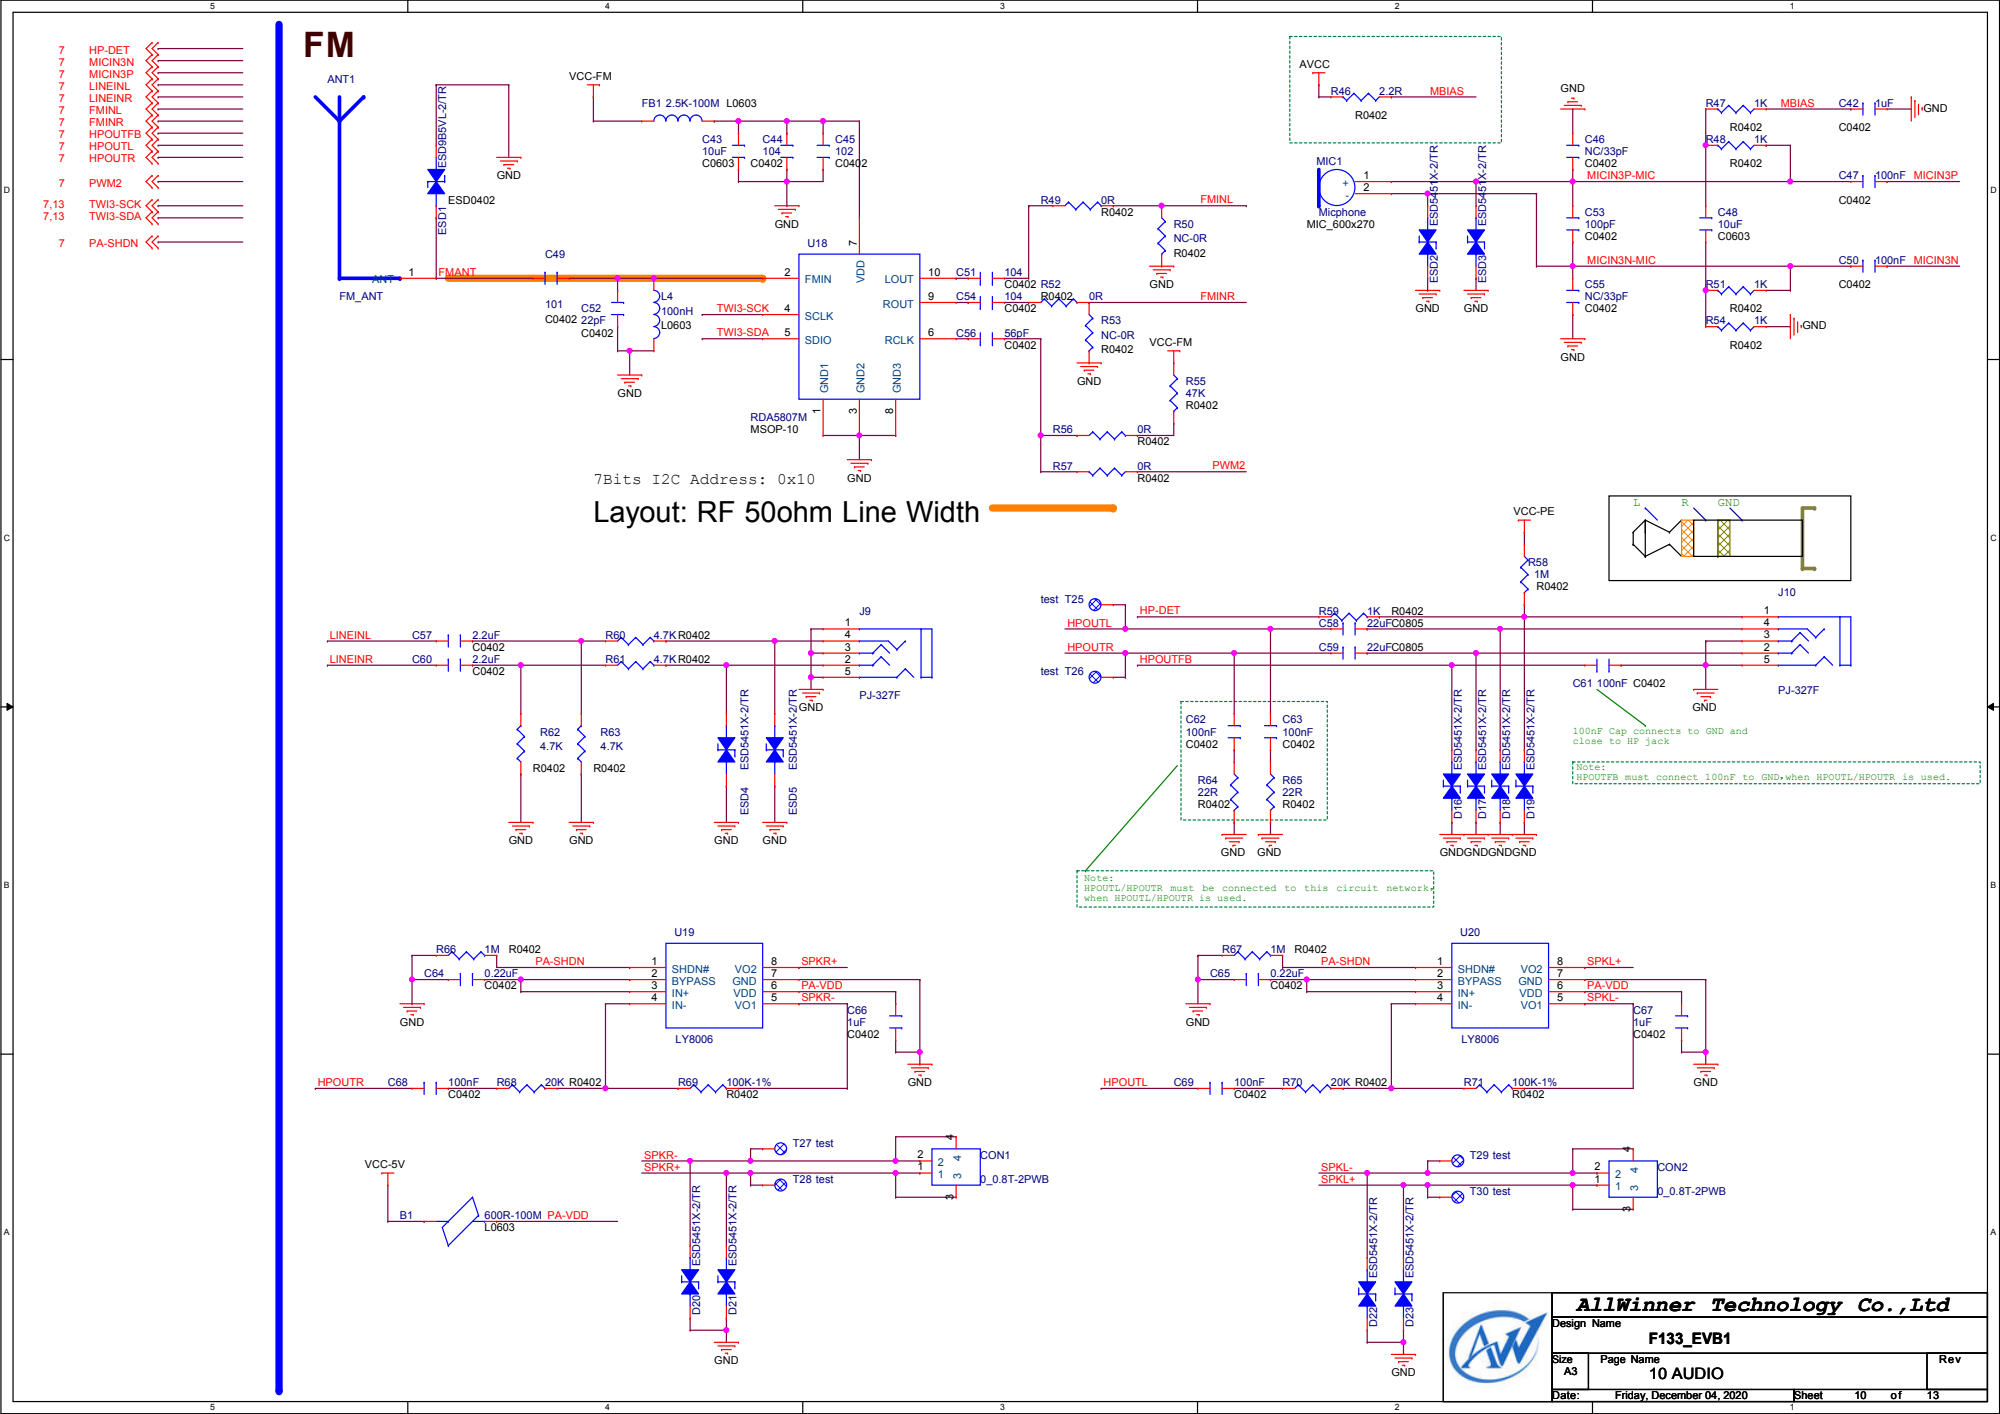
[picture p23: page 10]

100nF Cap connects to GND and
close to HP jack

Note:
HPOUTFB must connect 100nF to GND，when HPOUTL/HPOUTR is used.

HPOUTL/HPOUTR must be connected to this circuit network，
when HPOUTL/HPOUTR is used.

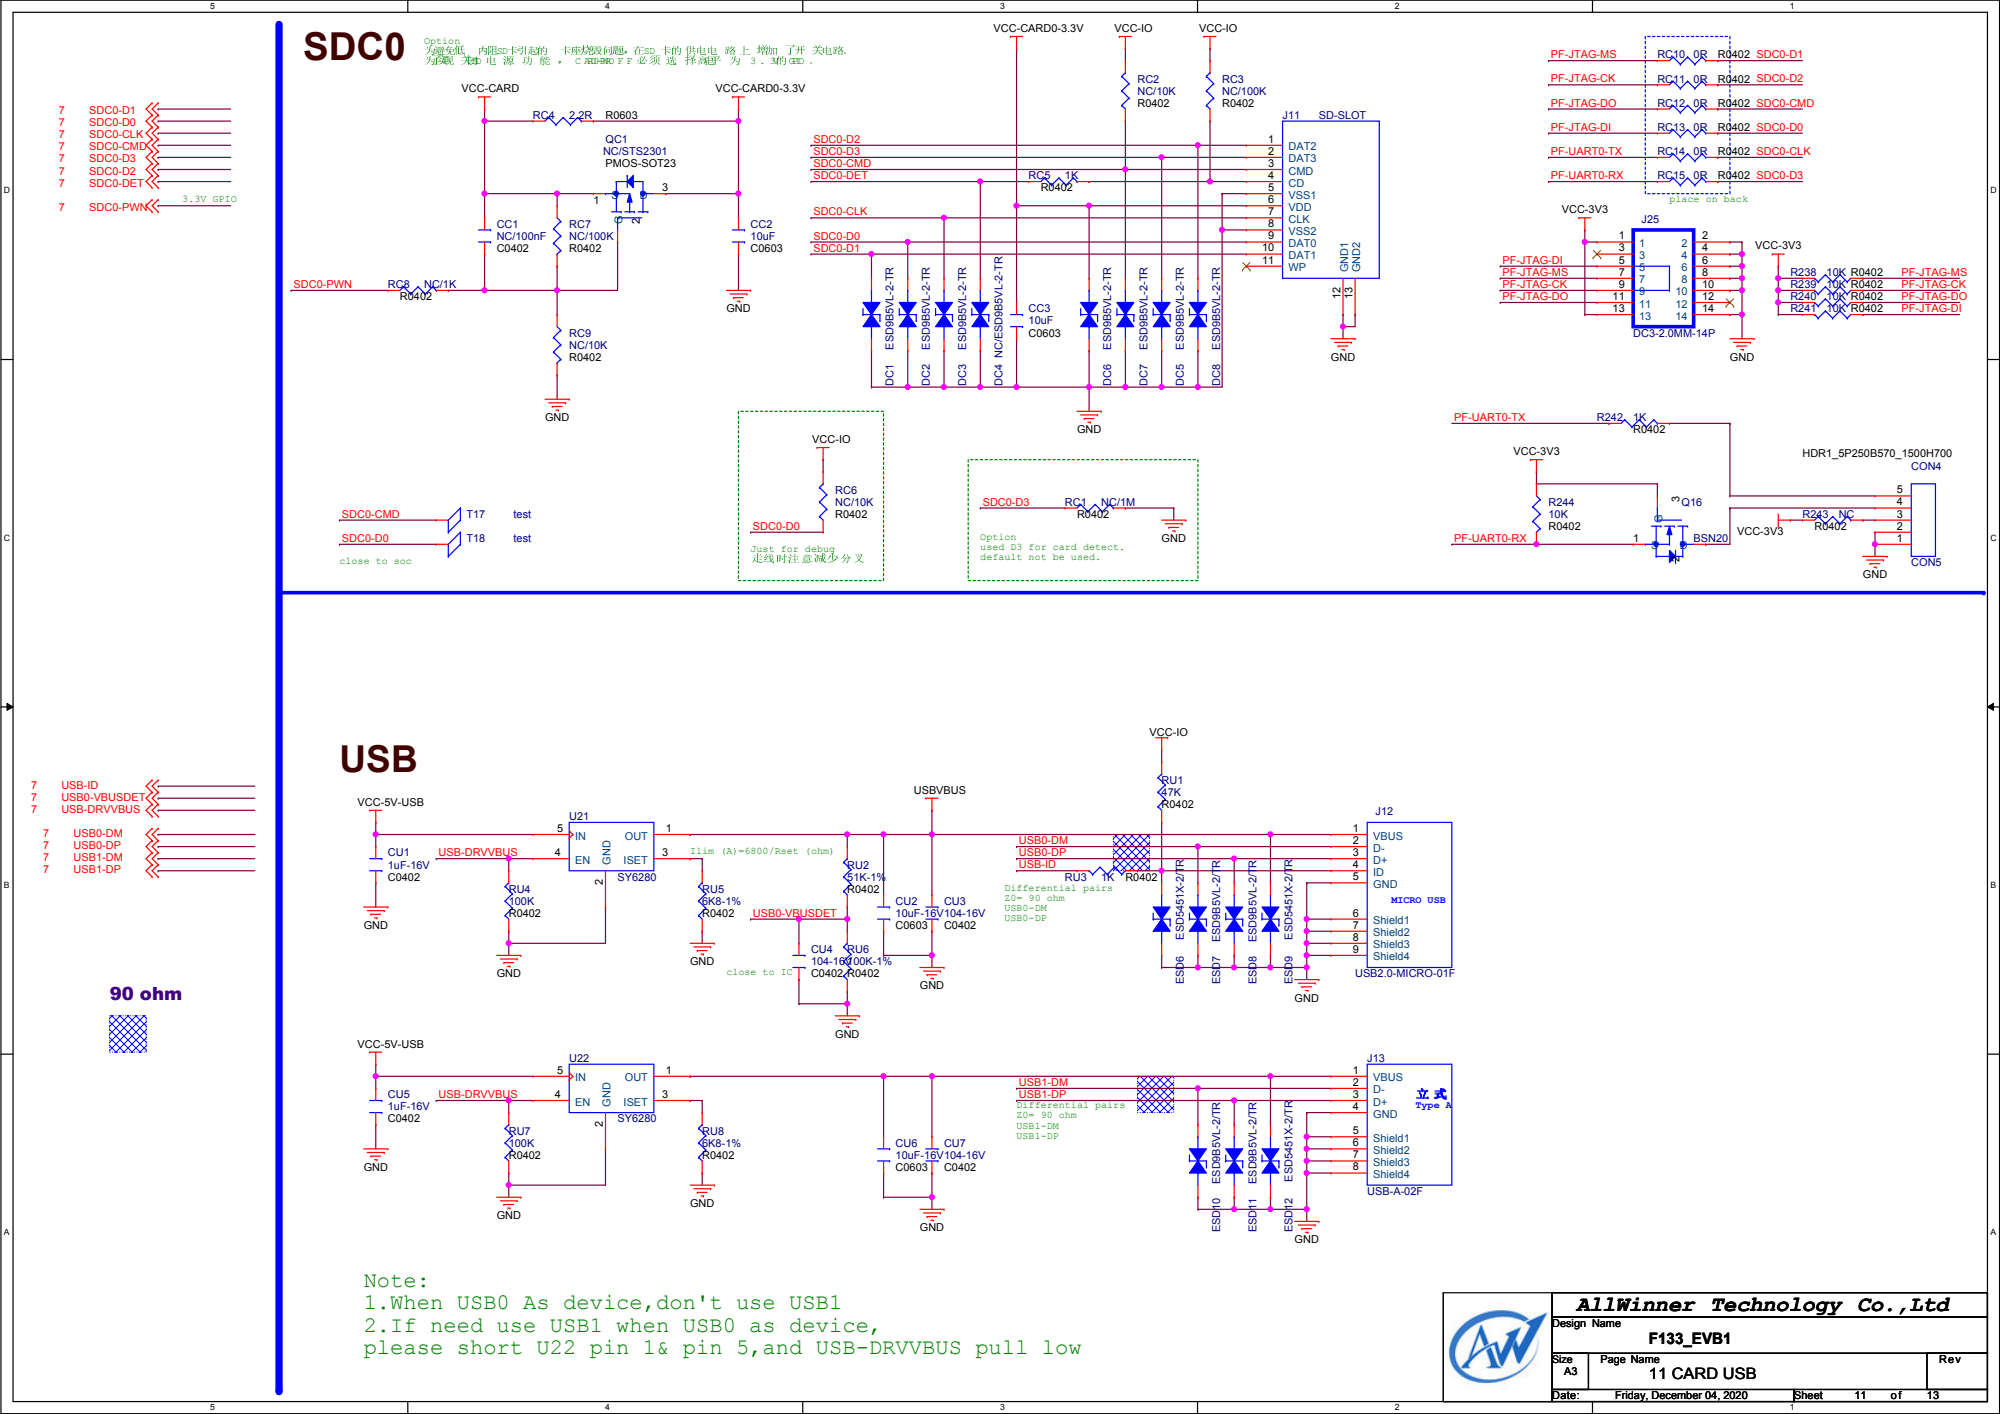
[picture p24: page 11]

Option
used D3 for card detect.

Note:
1.When USB0 As device,don't use USB1
2.If need use USB1 when USB0 as device,
please short U22 pin 1& pin 5,and USB-DRVVBUS pull low

## Place capacitors near the IC
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

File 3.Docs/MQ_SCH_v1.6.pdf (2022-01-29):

# 10uFC30

# 0.1uF R11

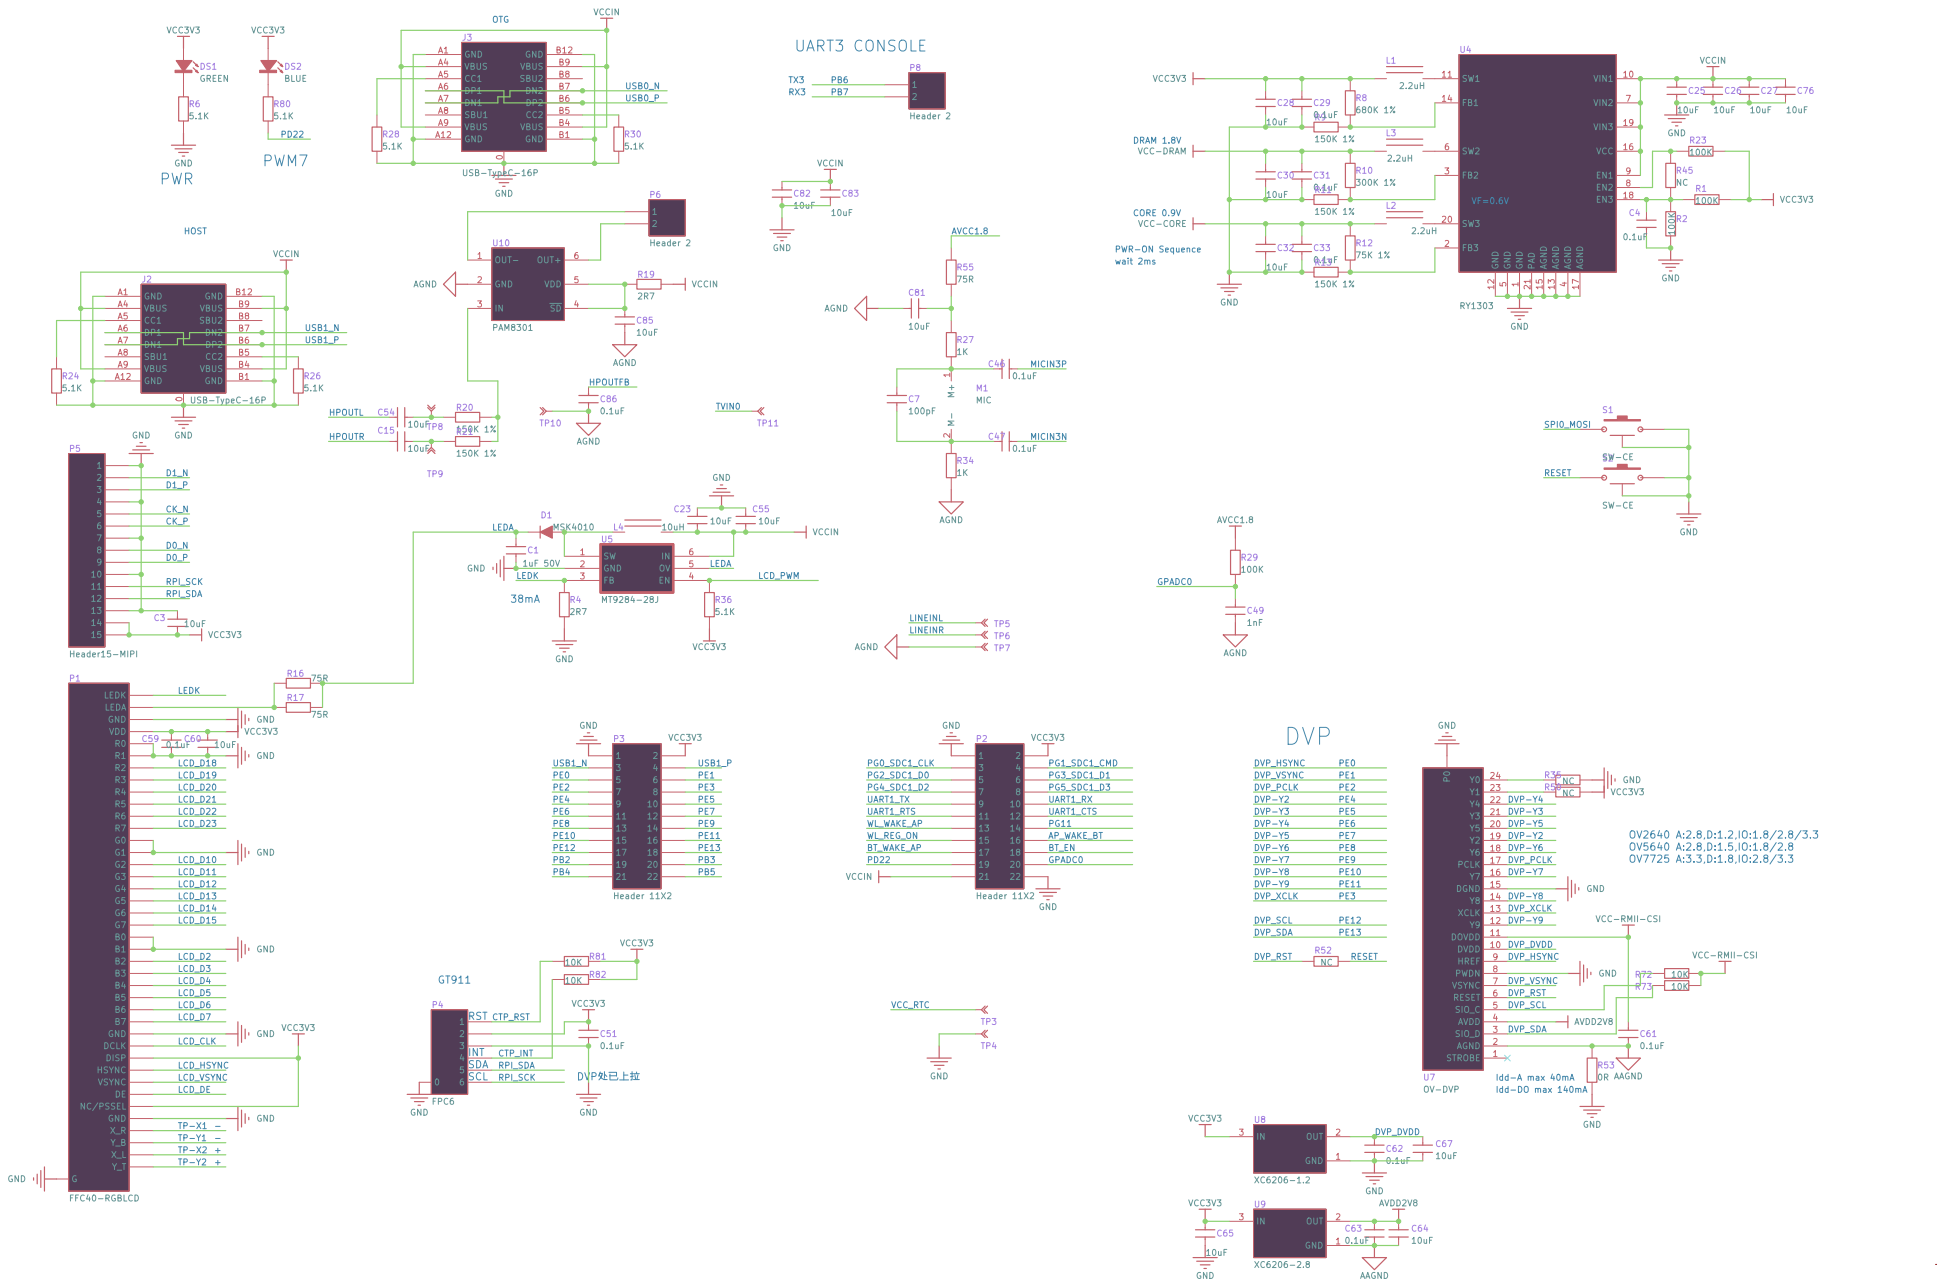
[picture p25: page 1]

0 GND A1 GND A12 VBUS A4 CC1 A5 DP1 A6 DN1 A7 SBU1 A8 VBUS A9 GND B1 GND B12 VBUS B4 CC2 B5 DP2 B6 DN2 B7 SBU2 B8 VBUS B9

1 VIN1 10 SW1 11 GND 12 AGND 13 FB1 14 AGND 15 VCC 16 AGND 17 EN3 18 VIN3 19 FB3 2 SW3 20 PAD 21 FB2 3 AGND

PWR-ON Sequence wait 2ms CORE 0.9V

VCC-RMII-CSI

VSYNC
DE NC/PSSEL GND

VCC3V3 | R84 NC
100K R¹⁴ NC/100K GND | R⁶⁸ ⁴⁷K

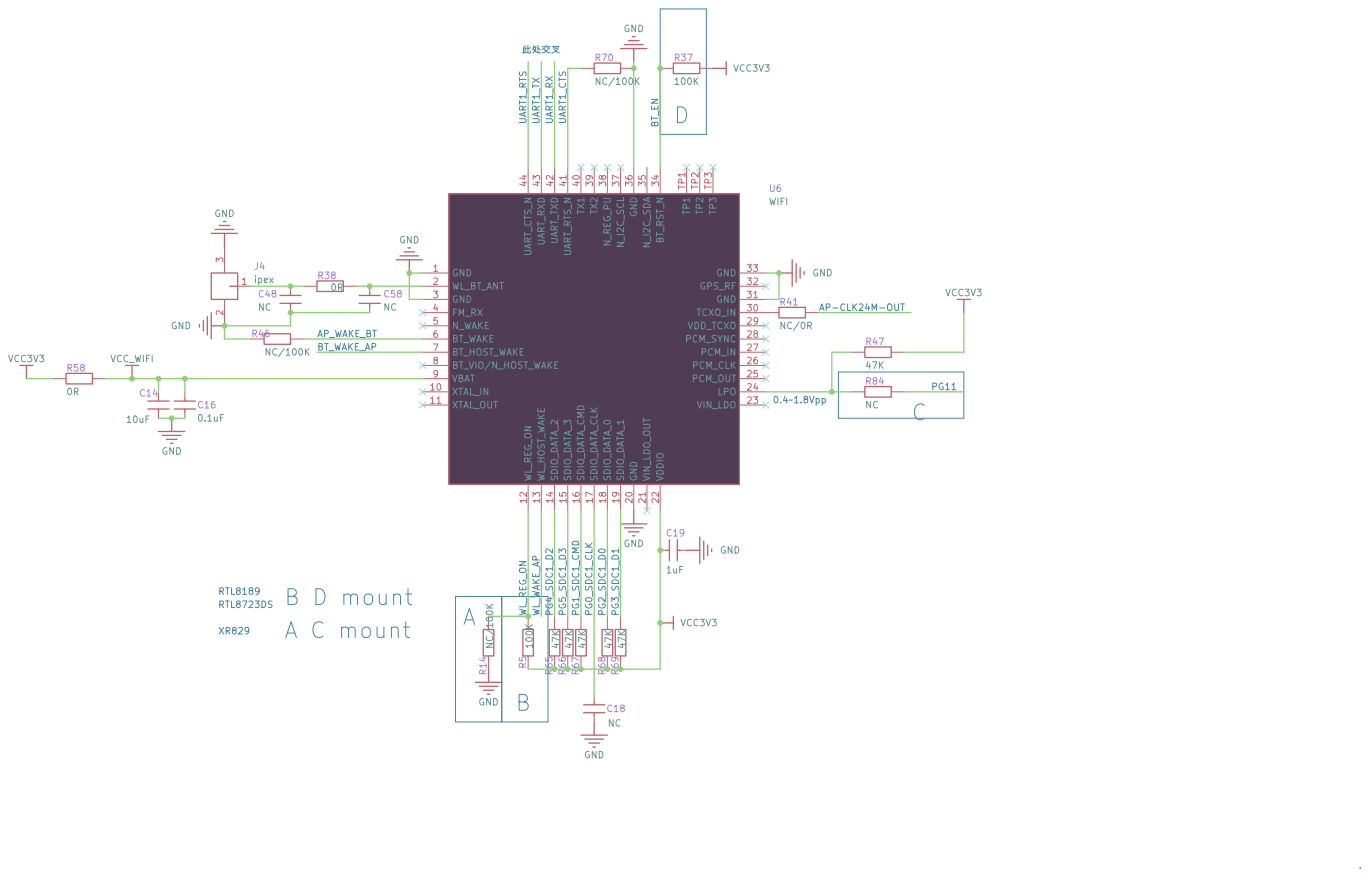
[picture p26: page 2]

þÿkdYN¤SÉ
R70 NC/100K R⁶⁵ ⁴⁷K R⁵ ¹⁰⁰K

# 0.1uFR48

# 10K GND


OV2640 IO:1.8/2.8/3.3 CSI/UART1245/TWI9123/PWM234/RMII OV7725 IO:2.5-3.3

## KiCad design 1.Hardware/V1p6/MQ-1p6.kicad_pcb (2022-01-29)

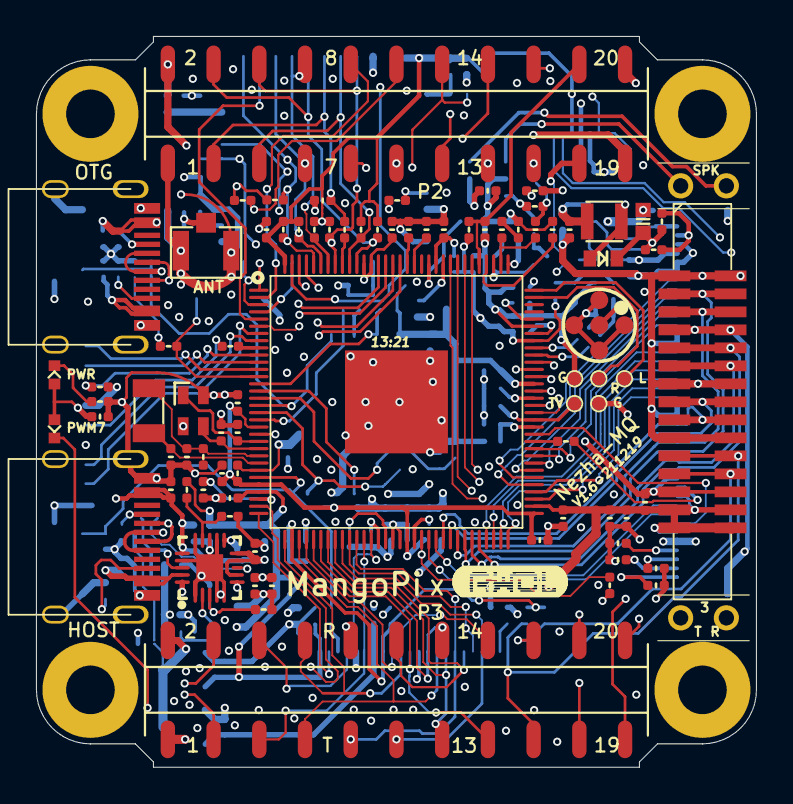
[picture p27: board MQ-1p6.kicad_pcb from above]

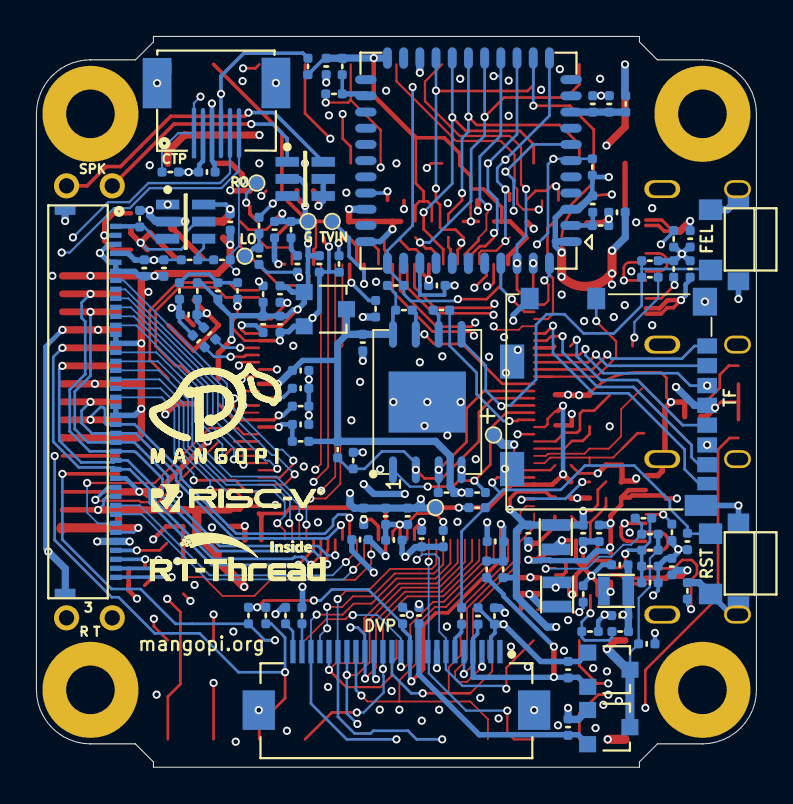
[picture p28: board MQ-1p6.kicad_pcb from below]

Board: 4 copper layers, 40.0 x 40.6 mm, 204 parts (120 on the bottom side), 160 nets.

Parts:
C1: 1uF 50V; C0603
C2, C3, C10, C14, C15, C21, C23, C25, C26, C27, C28, C30, C32, C54, C55, C60, C64, C65, C67, C76, C81, C82, C83, C85: 10uF; C0402
C4, C5, C6, C12, C13, C16, C20, C29, C31, C33, C34, C35, C36, C37, C38, C39, C41, C42, C46, C47, C51, C52, C53, C59, C61, C62, C63, C66, C70, C77, C79, C80, C84, C86: 0.1uF; C0402
C7: 100pF; C0402
C8, C9, C43, C45: 22pF; C0402
C11, C22, C44, C50, C68: 2.2uF; C0402
C18, C48, C58: NC; C0402
C19, C24, C69, C71: 1uF; C0402
C40, C78: 0.47uF; C0402
C49, C72, C73, C74, C75: 1nF; C0402
D1: MSK4010; SOD523
DS1: GREEN; LED0402
DS2: BLUE; LED0402
J1: TF5033981892; TFCARD-1040310811
J2, J3: USB-TypeC-16P; USB-TYPEC-16P
J4: ipex; I-PEX SOCKET
L1, L2, L3: 2.2uH; VLS2016
L4: 10uH; VLS252010
M1: MIC; MIC-T
P1: FFC40-RGBLCD; FFC{slash}SM0.5-1H40
P2: Header 11X2; _×ÊÁÏ¿â_ADLIB_A.PcbLib_HDR2X11T
P3: Header 11X2; _ÏîÄ¿_ADLIB_A.Pc_HDR2X11T
P4: FPC6
P5: Header15-MIPI; MIPI_CSI_1.0_30PIN
P6, P8: Header 2; HDR1X2-XIAO
R1, R2, R5, R23, R29, R37: 100K; R0402
R3, R39, R43, R49, R59, R64: 33R; R0402
R4, R19: 2R7; R0402
R6, R24, R26, R28, R30, R36, R80: 5.1K; R0402
R7, R18, R25, R33, R48, R72, R73, R74, R75, R78, R81, R82: 10K; R0402
R8, R40: 680K 1%; R0402
R9, R11, R13, R20, R21: 150K 1%; R0402
R10: 300K 1%; R0402
R12: 75K 1%; R0402
R14, R46, R70: NC/100K; R0402
R15, R38, R53, R56, R58, R61, R71, R79: 0R; R0402
R16, R17, R55, R60: 75R; R0402
R27, R34: 1K; R0402
R32, R35, R45, R50, R52, R57, R76, R77, R84: NC; R0402
R41: NC/0R; R0402
R42: 240R 1%; R0402
R47, R65, R66, R67, R68, R69: 47K; R0402
R54: NC/1K; R0402
S1, S2: SW-CE; MINISW
TP1, TP2, TP3, TP4, TP5, TP6, TP7, TP8, TP9, TP10, TP11: TEST POINT; TEST-POINT
U1: D1s-eLQFP128; QFP129P40B1600_1600H160
U2: XC6206-1.8V; SOT23
U3: SPIFLASH_SOP8W; WSON-SPIFLASH
U4: RY1303; QFN40P300X300X80_HS-21N
U5: MT9284-28J; SOT23-6
U6: WIFI; _×ÊÁÏ¿â_ADLIB_A.PcbLib_AP6212
U7: OV-DVP; FFC{slash}SM0.5-2H24-OV5640
U8: XC6206-1.2; SOT23
U9: XC6206-2.8; SOT23
U10: PAM8301; SOT23-6
X1: XTAL2520-24M CL=18PF; XTAL2520
XT1: 32.768K CL=12.5pF; Y3215

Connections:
32I: C45.1, R40.2, U1.25, XT1.1
32O: C43.1, R40.1, U1.24, XT1.2
AAGND: C61.1, C63.1, C64.2, R53.1, U7.2, U9.1
AGND: C5.1, C11.2, C22.1, C40.1, C49.1, C78.2, C81.2, C85.2, C86.1, R3.2, R15.2, R34.2, R64.2, TP7.1, TP10.1, U1.91, U2.1, U10.2
AP-CLK24M-OUT: R41.1, U1.21
AP_WAKE_BT: P2.16, R46.1, U1.125, U6.6
AVCC1.8: C5.2, C11.1, C22.2, R29.2, R55.1, R71.2, U1.89, U1.97, U2.2
AVDD2V8: C63.2, C64.1, R56.2, U7.4, U9.2
BT_EN: P2.18, R37.2, U1.127, U6.34
BT_WAKE_AP: P2.17, U1.126, U6.7
CK_N: P1.28, P5.5, U1.60
CK_P: P1.27, P5.6, U1.59
CTP_INT: P3.20, P4.4, R82.1, U1.85
CTP_RST: P3.19, P4.1, R81.1, U1.86
D0_N: P1.24, P5.8, U1.56
D0_P: P1.23, P5.9, U1.55
D1_N: P1.26, P5.2, U1.58
D1_P: P1.25, P5.3, U1.57
DVP-Y2: P3.9, U1.43, U7.19
DVP-Y3: P3.10, U1.42, U7.21
DVP-Y4: P3.11, U1.41, U7.22
DVP-Y5: P3.12, U1.40, U7.20
DVP-Y6: P3.13, U1.39, U7.18
DVP-Y7: P3.14, U1.38, U7.16
DVP-Y8: P3.15, U1.37, U7.14
DVP-Y9: P3.16, U1.36, U7.12
DVP_DVDD: C62.2, C67.1, U7.10, U8.2
DVP_HSYNC: P3.5, U1.44, U7.9
DVP_PCLK: P3.7, U1.35, U7.17
DVP_RST: R52.1, U7.6
DVP_SCL: P3.17, P4.6, P5.11, R72.1, U1.32, U7.5
DVP_SDA: P3.18, P4.5, P5.12, R73.1, U1.31, U7.3
DVP_VSYNC: P3.6, U1.45, U7.7
DVP_XCLK: P3.8, U1.33, U7.13
GND: C1.2, C2.1, C3.2, C4.1, C8.2, C9.2, C10.1, C12.1, C13.1, C14.1, C16.1, C18.1, C19.1, C20.1, C21.1, C23.2, C24.1, C25.2, C26.2, C27.2, C28.2, C29.1, C30.2, C31.1, C32.2, C33.1, C34.1, C35.1, C36.1, C37.1, C38.1, C39.1, C41.2, C42.1, C43.2, C44.2, C45.2, C48.1, C50.2, C51.1, C52.1, C53.1, C55.1, C58.1, C59.2, C60.1, C62.1, C65.2, C66.1, C67.2, C68.2, C69.2, C70.2, C71.2, C72.2, C73.2, C74.2, C75.2, C76.2, C77.1, C79.2, C82.2, C83.2, C84.2, J1.6, J1.G1, J1.G2, J1.G3, J1.G4, J1.G5, J2.0, J2.A1, J2.A12, J2.B1, J2.B12, J3.0, J3.A1, J3.A12, J3.B1, J3.B12, J4.2, J4.3, P1.3, P1.5, P1.6, P1.13, P1.14, P1.21, P1.22, P1.29, P1.36, P1.G, P2.1, P2.22, P3.1, P4.0, P4.3, P5.1, P5.4, P5.7, P5.10, P5.13, R2.2, R4.1, R6.2, R9.2, R11.2, R13.2, R14.1, R15.1, R24.2, R26.2, R28.2, R30.2, R35.2, R42.1, R46.2, R53.2, R54.2, R60.1, R70.1, R76.2, R78.2, S1.0, S1.1, S2.0, S2.2, TP2.1, TP4.1, U1.129, U3.4, U4.1, U4.4, U4.5, U4.12, U4.13, U4.15, U4.17, U4.21, U5.2, U6.1, U6.3, U6.20, U6.31, U6.33, U6.36, U7.8, U7.15, U7.P0, U8.1, X1.2, X1.4
GPADC0: C49.2, P2.20, R29.1, U1.101
HPOUTFB: C86.2, U1.100
HPOUTL: C54.1, C80.1, U1.99
HPOUTR: C6.1, C15.1, U1.98
LCD_CLK: P1.30, R59.2
LCD_D10: P1.15, U1.61
LCD_D11: P1.16, U1.62
LCD_D12: P1.17, U1.63
LCD_D13: P1.18, U1.64
LCD_D14: P1.19, U1.67
LCD_D15: P1.20, U1.68
LCD_D18: P1.7, U1.70
LCD_D19: P1.8, U1.69
LCD_D20: P1.9, U1.71
LCD_D21: P1.10, U1.72
LCD_D22: P1.11, U1.73
LCD_D23: P1.12, U1.74
LCD_DE: P1.34, U1.76
LCD_HSYNC: P1.32, U1.54
LCD_PWM: R32.2, R36.2, U5.4
LCD_VSYNC: P1.33, U1.53
LDOA-OUT: C13.2, C44.1, C77.2, C79.1, R61.2, R74.1, U1.20, U1.28, U1.50, U1.65
LEDA: C1.1, D1.K, R16.2, R17.2, U5.5
LEDK: P1.1, R4.2, U5.3
LINEINL: TP5.1, U1.96
LINEINR: TP6.1, U1.95
MICIN3N: C47.2, U1.88
MICIN3P: C46.2, U1.87
NetC4_2: C4.2, R1.2, R2.1, R45.2, U4.18
NetC6_2: C6.2, R3.1
NetC7_1: C7.1, C46.1, M1.1, R27.2
NetC7_2: C7.2, C47.1, M1.2, R34.1
NetC12_2: C12.2, R79.1, U1.77
NetC15_2: C15.2, R21.2, TP9.1
NetC40_2: C40.2, U1.92
NetC48_2: C48.2, J4.1, R38.2
NetC50_1: C50.1, U1.30
NetC54_2: C54.2, R20.2, TP8.1
NetC58_2: C58.2, R38.1, U6.2
NetC70_1: C70.1, R71.1, U1.107
NetC78_1: C78.1, U1.90
NetC80_2: C80.2, R64.1
NetC81_1: C81.1, R27.1, R55.2
NetC85_1: C85.1, R19.2, U10.4, U10.5
NetD1_A: D1.A, L4.2, U5.1
NetDS1_K: DS1.K, R6.1
NetDS2_K: DS2.K, R80.1
NetJ2_A5: J2.A5, R24.1
NetJ2_B5: J2.B5, R26.1
NetJ3_A5: J3.A5, R28.1
NetJ3_B5: J3.B5, R30.1
NetL1_1: L1.1, U4.11
NetL2_1: L2.1, U4.20
NetL3_1: L3.1, U4.6
NetP1_2: P1.2, R16.1, R17.1
NetP6_1: P6.1, U10.1
NetP6_2: P6.2, U10.6
NetR8_2: R8.2, R9.1, U4.14
NetR10_2: R10.2, R11.1, U4.3
NetR12_2: R12.2, R13.1, U4.2
NetR20_1: R20.1, R21.1, U10.3
NetR23_2: R23.2, R45.1, U4.8
NetR35_1: R35.1, U7.24
NetR39_1: R39.1, U1.120
NetR41_2: R41.2, U6.30
NetR42_2: R42.2, U1.47
NetR43_2: R43.2, U1.9
NetR47_1: R47.1, R84.2, U6.24
NetR49_1: R49.1, U1.19
NetR50_1: R50.1, U7.23
NetR54_1: R54.1, U1.106
NetR59_1: R59.1, U1.75
PB4: P3.21, U1.84
PB5: P3.22, U1.82
PB6: P8.1, U1.80
PB7: P8.2, U1.79
PD22: P2.19, R32.1, R80.2, U1.52
PG0_SDC1_CLK: C18.2, P2.3, R39.2, U6.17
PG1_SDC1_CMD: P2.4, R67.2, U1.118, U6.16
PG2_SDC1_D0: P2.5, R68.2, U1.119, U6.18
PG3_SDC1_D1: P2.6, R69.2, U1.121, U6.19
PG4_SDC1_D2: P2.7, R65.2, U1.123, U6.14
PG5_SDC1_D3: P2.8, R66.2, U1.122, U6.15
PG11: P2.14, R84.1, U1.6
RESET: C84.1, R52.2, R74.2, S2.1, U1.27
SDC0_CLK: J1.5, R43.1
SDC0_CMD: J1.3, R18.2, U1.10
SDC0_D0: J1.7, U1.8
SDC0_D1: J1.8, U1.7
SDC0_D2: J1.1, U1.12
SDC0_D3: J1.2, U1.11
SDC0_DET: J1.G6, R48.1, U1.13
SPI0_CLK: R49.2, U3.6
SPI0_CS: R7.1, U1.18, U3.1
SPI0_HOLD: R25.2, U1.14, U3.7
SPI0_MISO: R75.2, R76.1, U1.16, U3.2
SPI0_MOSI: R77.2, R78.1, S1.2, U1.17, U3.5
SPI0_WP: R33.1, U1.15, U3.3
TP-X1: C75.1, P1.37, U1.102
TP-X2: C74.1, P1.39, U1.103
TP-Y1: C73.1, P1.38, U1.104
TP-Y2: C72.1, P1.40, U1.105
TVIN0: TP11.1, U1.108
TVIN_VRN: C71.1, U1.111
TVIN_VRP: C69.1, U1.110
TV_OUT: R60.2, TP1.1, U1.78
UART1_CTS: P2.12, R70.2, U1.4, U6.41
UART1_RTS: P2.11, U1.3, U6.44
UART1_RX: P2.10, U1.2, U6.42
UART1_TX: P2.9, U1.1, U6.43
USB0_N: J3.A7, J3.B7, U1.114
USB0_P: J3.A6, J3.B6, U1.115
USB1_N: J2.A7, J2.B7, P3.3, U1.113
USB1_P: J2.A6, J2.B6, P3.4, U1.112
VCC3V3: C2.2, C3.1, C19.2, C20.2, C28.1, C29.2, C34.2, C35.2, C36.2, C41.1, C42.2, C51.2, C59.1, C60.2, C65.1, C68.1, DS1.A, DS2.A, J1.4, L1.2, P1.4, P1.31, P1.35, P2.2, P3.2, P4.2, P5.14, P5.15, R1.1, R5.1, R7.2, R8.1, R18.1, R23.1, R25.1, R33.2, R36.1, R37.1, R47.2, R48.2, R50.2, R57.1, R58.2, R65.1, R66.1, R67.1, R68.1, R69.1, R75.1, R77.1, R79.2, R81.2, R82.2, U1.29, U1.66, U1.83, U1.128, U2.3, U3.8, U6.22, U8.3, U9.3
VCC-CORE: C10.2, C32.1, C33.2, C37.2, C38.2, C39.2, C53.2, L2.2, R12.1, U1.46, U1.51, U1.81, U1.116, U1.117
VCC-DRAM: C21.2, C24.2, C30.1, C31.2, C52.2, L3.2, R10.1, U1.48, U1.49
VCC-RMII-CSI: C61.2, C66.2, R56.1, R57.2, R72.2, R73.2, U1.34, U7.11
VCCIN: C23.1, C25.1, C26.1, C27.1, C55.2, C76.1, C82.1, C83.1, J2.A4, J2.A9, J2.B4, J2.B9, J3.A4, J3.A9, J3.B4, J3.B9, L4.1, P2.21, R19.1, U4.7, U4.9, U4.10, U4.16, U4.19, U5.6
VCC_RTC: R61.1, TP3.1, U1.26
VCC_WIFI: C14.2, C16.2, R58.1, U6.9
WL_REG_ON: P2.15, R5.2, R14.2, U1.124, U6.12
WL_WAKE_AP: P2.13, U1.5, U6.13
XI: C9.1, U1.23, X1.3
XO: C8.1, U1.22, X1.1
